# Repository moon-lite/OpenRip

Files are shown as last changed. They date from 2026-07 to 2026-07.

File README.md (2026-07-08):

# OpenRip

**Open-source launch telemetry for Beyblade X.** A ~$20 module that mounts
on top of the winder launcher — touching nothing but the outside — and
measures your launch RPM, beaming it to a web app over Bluetooth. No app
store, no account, no proprietary anything.

Think of it as an open alternative to the official Beybattle Pass — build
it, hack it, own your data — plus measurements the official one doesn't
take.

> ⚠️ **Project status: early prototype.** The firmware and web app exist,
> and the sensing approach is proven on a real launcher — a breadboard
> build reads clean RPM off the factory optical encoder (zero
> modification). There's no printed housing yet, so nothing here is ready
> to build unless you enjoy breadboards. Watch/star the repo to catch the
> first buildable release.

## What it does

- **Peak and release RPM** from an IR sensor reading the winder launcher's
  **factory encoder disc** through its built-in window — the exact surface
  the official module reads. **Zero launcher modification** (targeting ±2%
  of the official numbers)
- **True launch detection**: a low-force switch rides the launcher's
  bey-presence plunger, so tracking arms when a bey locks in and the
  release moment is timestamped — winding and re-insertion can't fake a
  launch
- **Live RPM + launch history** in a [web app](https://moon-lite.github.io/OpenRip/)
  that connects straight from Chrome — history stays in your browser, exports
  to CSV
- **Coming in v0.2:** launch angle relative to the stadium floor, and a rip
  smoothness score, via an IMU — data the official module doesn't capture

## What's in the box

| | |
|---|---|
| Brains | Seeed XIAO ESP32-C3 (~$5) |
| Sensor | TCRT5000 IR reflective sensor over the encoder window (~$1.50) |
| Presence | Subminiature microswitch riding the bey-release plunger (~$2) |
| Power | 100mAh LiPo, charges over USB-C (~$4) |
| Body | 3D-printed shell mounting on the winder launcher's top face |

Full parts list in [`hardware/BOM.csv`](hardware/BOM.csv), wiring in
[`hardware/wiring.md`](hardware/wiring.md).

## Try the app

The web app is live at **[moon-lite.github.io/OpenRip](https://moon-lite.github.io/OpenRip/)** —
no hardware needed to poke around: hit **SIM LAUNCH** to see it work.
Real connections need Chrome or Edge (Web Bluetooth doesn't exist on iOS).

## Roadmap

1. ✅ Firmware + web app written
2. ✅ **M0a: launcher characterized** — it has a factory optical encoder on
   the hook shaft, readable through a top-face window, plus a bey-presence
   plunger we piggyback for launch detection
3. ✅ **M0b: signal proof** — clean pulse train confirmed off a real
   launcher, launch RPM readings landing in the expected range
4. Printed housing + battery → first real device
   ← we are here
5. Public v0.1: build guide, video, flash-from-browser
6. v0.2: IMU for launch angle + smoothness

Details live in [SPEC.md](SPEC.md); build instructions grow in
[`docs/build-guide.md`](docs/build-guide.md) as each stage lands.

## For developers

```sh
cd firmware
pio run                 # build (serial-only)
pio run -t upload       # flash over USB-C
pio device monitor      # launch summaries at 115200 baud
```

Flashing from the browser (ESP Web Tools) ships with the first release —
the page is already stubbed at [`app/flash/`](app/flash/).

## Legal

BEYBLADE, BEYBLADE X, and BEYBATTLE PASS are trademarks of Tomy Company,
Ltd. and/or its licensee Hasbro, Inc. This project is not affiliated with,
sponsored by, or endorsed by either company; the names are used only to
describe compatibility ("works with Beyblade X winder launchers"). All
other trademarks are the property of their respective owners.

Licenses: firmware and app are MIT (see [LICENSE](LICENSE)); hardware and
models are CERN-OHL-P v2 (see [hardware/LICENSE](hardware/LICENSE) and
[models/LICENSE](models/LICENSE)).

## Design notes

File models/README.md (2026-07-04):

# Models

Housing CAD lands at M1: STEP + STL + Fusion source (.f3d), per SPEC.md §6.
Two-part clip-on shell (sensor arm + electronics bay) for the Takara Tomy
string launcher grip rail. Empty until sensor placement is validated at M0.

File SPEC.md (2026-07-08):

# OpenRip — Open Source Launch Telemetry for Beyblade X

**Status:** Draft v0.1 · **Licenses:** MIT (firmware/app), CERN-OHL-P v2 (hardware/models)

An open-source launcher-mounted module that measures launch RPM and launch angle for Beyblade X, reporting over BLE. Functional alternative to the official Beybattle Pass (BX-09) with data it doesn't capture (IMU) and an open protocol.

> Naming note: BEYBLADE, BEYBLADE X, and BEYBATTLE PASS are trademarks of Tomy Company, Ltd. and/or its licensee Hasbro, Inc. The official accessory's correct name is "Beybattle Pass" — always call it that (not "BattlePass"). Project name and repo must never use these marks except descriptively/nominatively ("compatible with Beyblade X launchers", "alternative to the official Beybattle Pass") and must never brand this project or its parts with them. Avoid Hasbro's slogan "LET IT RIP!" in product copy.

---

## 1. Goals

- **Zero launcher modification (hard requirement):** the device attaches externally (top-face mount over the factory encoder window) — nothing glued, pressed on, or altered. This is what keeps tournament use on the table.
- Measure peak launch RPM with accuracy comparable to the official Beybattle Pass (±2% target)
- Measure launch angle relative to a calibrated stadium plane
- Capture rip motion profile (accel curve, smoothness/consistency score)
- Report over BLE to a Web Bluetooth app — no app store, no account
- Fully reproducible from the repo: ~$20 in parts, a 3D printer, basic soldering
- Non-devs can flash firmware from a browser (ESP Web Tools)

## 2. Non-Goals (v0.x)

- String launcher support — v0.1 targets the winder launcher only (it has the factory optical encoder + window the sensor reads; string launcher sensing is a separate problem)
- Bey-side sensing (MEMS gyros saturate ~333 RPM; bey spins 5–12k)
- Position tracking / dead reckoning (IMU drift makes it useless)
- Battle outcome simulation — contact physics is out of scope
- Official app compatibility (protocol mimicry is a maybe-later, see §9)
- iOS support in v0.1 (Web Bluetooth is dead on iOS Safari)

## 3. Hardware

### v0.1 — Spin only (prototype)
| Part | Component | Est. cost |
|---|---|---|
| MCU | Seeed XIAO ESP32-C3 | $5 |
| Spin sensor | TCRT5000 IR reflective sensor, reading the winder launcher's **factory optical encoder** — a black/white two-segment disc visible through a ~5×5mm clear window on the top face, disc surface ~3mm below the window (this is what the official device reads; launcher stays stock). Peak sensitivity ~2.5mm matches the recess. Fallback: ITR8307 if the TCRT5000's signal swing is poor. | $1 |
| Bey presence | Subminiature low-force lever microswitch (SPDT, <0.5N actuation, Omron SS-01GL class) riding the launcher's spring plunger next to the encoder window — plunger sits below flush when empty, above flush with a bey locked, drops on release. Gates launch detection and timestamps release. | $1.50 |
| Battery | 401030 LiPo 100mAh (XIAO onboard charging) | $4 |
| Switch | SPDT slide | $0.50 |
| Housing | PLA, top-face mount over the encoder window (winder launcher) | ~$0.30 |

### v0.2 — Adds IMU
| Part | Component | Est. cost |
|---|---|---|
| IMU | LSM6DSO 6-axis (I2C) on launcher body | $5–8 |

**Signal-quality risk is now LOW** (M0a complete, 2026-07): the launcher ships with a purpose-built encoder disc — we're reading a surface designed to be read. The remaining unknown is IR contrast between the **translucent white** and black segments at the TCRT5000's wavelength (the disc was tuned for the official sensor, not ours); M0b measures it. Sticker fallbacks are obsolete.

### Small-batch path (later)
Custom PCB (ESP32-C3 module + bare LSM6DSO + TCRT5000), JLCPCB assembly: ~$8–12/unit @ qty 50.

## 4. Firmware

- **Stack:** PlatformIO, Arduino framework on ESP32-C3
- **RPM:** TCRT5000 reflectivity edges off the factory encoder disc → ADC threshold with hysteresis → interval timing. Two-segment disc = 1 pulse/encoder-rev; the disc sits on the hook shaft, so the window reads hook RPM directly (GEAR_RATIO = 1.0, kept configurable). Serial raw mode streams ADC samples for signal characterization.
- **Launch detection (presence-gated state machine):** IDLE → ARMED (plunger high = bey locked) → RIPPING (pulses while armed) → RELEASE (plunger falling edge). The release edge is timestamped; the record carries both **peak RPM** (min interval in the window) and **release RPM** (last pulse interval before the edge). Pulses are ignored while the plunger is low, which rejects winding/re-insertion as false launches. The 250ms pulse timeout survives only as a fallback when the release edge is missed; the switch input is debounced ~5ms. This matches the presumed official Beybattle Pass behavior (presence-gated tracking) and resolves the launch-detection ambiguity of a pure timeout.
- **IMU (v0.2):** LSM6DSO @ 416Hz over I2C, Madgwick fusion for orientation. Log accel/orientation ring buffer during rip; snapshot orientation at final encoder pulse = release angle.
- **Calibration:** button-triggered 2s rest on stadium floor (or rim jig) → zero orientation to stadium plane. Store in NVS.
- **BLE:** GATT server, custom service. Notify characteristic pushes a launch record post-launch; second characteristic for live RPM stream (training mode).
- **Power:** deep sleep after 5 min idle, wake on motion (IMU interrupt) or button.

### Launch record (v1 schema)
```
{
  seq: uint16,
  peak_rpm: uint16,
  release_rpm: uint16,       // from last pulse interval before the plunger release edge
  release_pitch_deg: int8,   // v0.2
  release_roll_deg: int8,    // v0.2
  rip_duration_ms: uint16,
  smoothness: uint8,         // 0-100, v0.2
  battery_pct: uint8
}
```

## 5. App

- **v0.1:** single-page Web Bluetooth app (vanilla JS or lightweight framework). Connect, live RPM, launch history in localStorage, CSV export.
- **Hosting:** GitHub Pages from the same repo.
- **v0.2+:** angle display, consistency graphs, session stats.

## 6. Housing

- Modeled in Fusion; publish **STEP + STL + source (.f3d)**
- Mounts on the **top face of the winder launcher**, over the factory encoder window — registers against the top-face geometry (not the grip rail)
- Holds the TCRT5000 centered over the ~5×5mm window at ~0mm standoff (sensor face flush to the window; the disc sits ~3mm below, at the sensor's sweet spot)
- Positions the bey-presence microswitch lever over the spring plunger adjacent to the window — actuated by the plunger's above-flush travel **without adding force that prevents bey seating** (low-force lever, free pivot)
- The microswitch mounts on an **adjustable carriage** (slot + M2 screw), not a fixed pocket: the plunger only rises ~1mm above flush, which is inside FDM print-tolerance stack-up. Builders calibrate the position once — slide until the switch **clicks with a bey seated and releases with it out** — then lock the screw.
- Two-part shell: sensor carrier + electronics bay
- Print settings documented; no supports as a design goal

## 7. Repo Layout

```
/firmware      PlatformIO project
/hardware      BOM.csv, wiring diagram, (later: KiCad)
/models        STEP, STL, Fusion source
/app           Web Bluetooth app (deployed via Pages)
/docs          Build guide, sensor placement photos, calibration
SPEC.md        this document
```

- GitHub Releases: firmware .bin + ESP Web Tools flash page per release
- Build guide gets a companion video (3 min, embedded in README)

## 8. Milestones

- **M0a — Mount characterization: ✅ complete (2026-07).** Winder launcher has a factory optical encoder — two-segment black/white disc through a ~5×5mm top-face window, disc ~3mm down. Findings: docs/sensor-characterization.md.
- **M0b — Sensor proof: ✅ complete (2026-07).** Breadboard IR sensor module (AO output) + ESP32: clean two-level signal off the encoder disc confirmed by hand-crank capture (tuned thresholds `SENSOR_THRESH_LOW 400` / `SENSOR_THRESH_HIGH 550`) and real launch RPM readings (peak 6746 and 6654, both within the expected 5,000–12,000 range). Findings: docs/sensor-characterization.md. *Go/no-go gate: passed.*
- **M1 — v0.1 device:** BLE launch records, printed housing, battery power
- **M2 — App:** Web Bluetooth page live on Pages, history + export
- **M3 — Public v0.1:** repo cleanup, build guide + video, ESP Web Tools flashing. Post to WBO + r/BeybladeX
- **M4 — v0.2 IMU:** angle, calibration, smoothness scoring
- **M5 (optional):** custom PCB + Tindie kits if community demand shows

## 9. Open Questions

1. Verify official Beybattle Pass mount geometry vs. designing our own top-face registration (affects M1 CAD)
2. SP↔RPM relationship — worth matching official app numbers for community comparability?
3. Mimic the reverse-engineered official BLE protocol (WBO thread) so community apps work, or stay clean with our own? Leaning own protocol + documented schema.
4. ~~Magnet on chuck: glue-on acceptable, or design a press-fit printed chuck sleeve so the launcher stays unmodified?~~ Superseded: any launcher modification is out (see Goals). Optical sensing through the mount opening replaces the magnet entirely.
5. ~~Pulses-per-rev off stock geometry~~ Resolved at M0a: two-segment encoder disc = 1 pulse per encoder rev. ~~Encoder-to-hook gear ratio~~ Resolved by teardown: the disc is mounted directly on the hook shaft (16T gear), downstream of the gear train — the window reads hook RPM directly (GEAR_RATIO = 1.0).
6. Tournament legality is TO-discretion even at zero modification — most rulesets allow *official* accessories, not arbitrary attachments. Frame the device as training/casual-legal, tournament-pending; zero modification keeps the door open, it doesn't guarantee entry.

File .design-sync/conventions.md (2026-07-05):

# open=rip design conventions

open=rip is a **light, airy, editorial** aesthetic — a clean zine, not a
dashboard. Paper-white ground, ink typography, hairline rules instead of
boxes, one teal accent for live data and the brand mark, italics for
captions and asides. Screens should read like a well-set magazine page
about your launches.

## Setup

No provider is required. Components style themselves via CSS custom
properties defined in `styles.css` (`:root` scope) — make sure that
stylesheet is loaded. **Give the page a paper ground**: set
`background: var(--or-bg)` on the page/root container; components assume a
light ground and look wrong on dark.

The single family (Instrument Sans, with true italics) loads via the Google
Fonts `@import` already inside `styles.css` — nothing to add. Hierarchy
comes from weight and rules, not color: 700 for numerals/headlines, 600 for
buttons, 500 for labels, 400 for body, *italic* for captions and notes.

## Styling idiom

There are **no utility classes**. Use the components' props for the
controls; for your own layout glue (containers, grids, spacing) write plain
CSS or inline styles using the tokens:

- Surfaces: `--or-bg` (paper), `--or-bg-raise` (white), `--or-line` (hairlines), `--or-line-strong` (ink rules)
- Ink: `--or-ink` (primary), `--or-ink-dim` (labels/captions)
- Signals: `--or-accent` (teal — brand, live data, links), `--or-accent-wash` (faint teal fill), `--or-danger` (coral — destructive only)
- Type: `--or-font` (the only family — vary weight and italic, not face)
- Spacing: `--or-space-xs/sm/md/lg/xl` (4/8/16/24/40px)
- Corners: `--or-radius-pill` (controls are pills), `--or-radius` (12px, rare — most surfaces are unboxed)

Prefer **rules over boxes**: separate sections with `Divider` or a 1px
`--or-line` border, not cards. Numerals get
`font-feature-settings: "tnum"` so columns align. Labels are small,
lowercase, `--or-ink-dim`. Generous whitespace — when in doubt, add space,
not decoration.

## Components (window.OpenRipDesign)

`Button` (variant: primary | ghost | danger — primary is the solid ink
pill, one per screen), `StatusChip` (online + label; hairline pill),
`Gauge` (value/max/unit/size — the hero readout, one per screen),
`StatTile` (label + value; top-rule index block, "—" for empty), `Divider`
(hairline ink rule), `Banner` (italic margin note with teal left rule),
`Wordmark` (the lowercase open=rip mark, top-left), `DataTable`
(columns/rows/emptyText — hairline rows, no box).

## Where the truth lives

Read `styles.css` (tokens at top, component classes below) before inventing
styles; per-component APIs are in each `<Name>.d.ts`.

## Idiomatic screen skeleton

```jsx
const { Wordmark, StatusChip, Button, Divider, Gauge, StatTile } = window.OpenRipDesign;

<div style={{ background: "var(--or-bg)", minHeight: "100vh", padding: "var(--or-space-xl)" }}>
  <header style={{ display: "flex", justifyContent: "space-between", alignItems: "flex-end", paddingBottom: "var(--or-space-md)" }}>
    <Wordmark subtitle="launch telemetry · vol 0.1" />
    <div style={{ display: "flex", gap: "var(--or-space-sm)", alignItems: "center" }}>
      <StatusChip online label="Linked" />
      <Button variant="primary">Disconnect</Button>
    </div>
  </header>
  <Divider />
  <main style={{ display: "flex", gap: "var(--or-space-xl)", alignItems: "center", padding: "var(--or-space-xl) 0" }}>
    <Gauge value={8450} unit="rpm · live" />
    <div style={{ display: "grid", gridTemplateColumns: "1fr 1fr", gap: "var(--or-space-lg)" }}>
      <StatTile label="session best" value="11,240" />
      <StatTile label="launches" value="14" />
    </div>
  </main>
</div>
```

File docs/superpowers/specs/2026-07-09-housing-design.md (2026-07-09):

# M1 Housing Design — Blender + MCP Workflow

**Status:** Approved (brainstorming session 2026-07-09) — implementation not yet started.

## Context

M0a (mount characterization) and M0b (sensor proof) are complete: the winder
launcher's factory optical encoder is confirmed readable through its
top-face window with zero modification, and a breadboard build has proven
clean RPM readings end-to-end, including presence-gated launch detection via
a microswitch on the launcher's spring plunger. See
`docs/sensor-characterization.md` for the validated data.

M1 is next per `SPEC.md` §8: printed housing, battery power, BLE launch
records. This spec covers only the **housing** piece of M1. No CAD exists
yet — `models/` currently holds only `LICENSE` and a stub `README.md`, and
that stub's description ("clip-on shell for the string launcher grip rail")
is stale/incorrect: `SPEC.md` §6 correctly specifies a **top-face** mount
over the encoder window, registering against top-face geometry, not the
grip rail. This work corrects that stub as part of landing the real design.

## Goals

- Design a two-part printable shell that mounts non-destructively on the
  winder launcher's top face and holds:
  - the sensor breakout module (VCC/GND/AO/DO, onboard LM393 comparator —
    the part actually validated at M0b, not the bare TCRT5000 originally
    speced in the BOM) positioned over the ~5×5mm encoder window
  - the bey-presence microswitch on an adjustable carriage (slot + M2
    screw/heat-set insert), as already described in `docs/build-guide.md`
  - the Seeed XIAO ESP32-C3
  - the 401030 LiPo battery
  - an SPDT power slide switch
- Drive the modeling through Claude Code via a Blender MCP connection, using
  a phone-captured 3D scan of the launcher's top face as the registration
  reference surface, so the mount fits the launcher's real geometry rather
  than estimated dimensions.
- Deliver STEP + STL + Blender source (`.blend`), updating `SPEC.md` §6's
  deliverable format away from Fusion's `.f3d` (no longer applicable since
  we're not using Fusion 360).

## Non-goals

- Finalizing the exact registration/clip geometry in this document — that's
  a first-CAD-iteration decision, made after the scan data exists, not
  something to lock in blind.
- IMU mounting — that's M4/v0.2 scope, not this milestone.
- Any launcher modification. Zero-modification is a hard requirement
  (`SPEC.md` §1) carried over unchanged: the mount must be a removable,
  non-destructive friction-fit/clip — nothing glued, nothing pressed in
  permanently, nothing altered on the launcher itself.

## Decisions from brainstorming

- **Geometry source:** phone 3D scan (LiDAR/photogrammetry) of the bare
  launcher top face, exported as a mesh (OBJ/STL).
- **Sensor footprint:** design around the breakout module already wired and
  validated at M0b, not the bare TCRT5000 from the original BOM. (BOM/
  wiring.md's "buy bare sensors, not modules" note is now superseded for
  this build and should be revisited/updated separately when this housing
  work lands.)
- **Print setup:** the builder has their own FDM printer, so a fast
  print-and-check iteration loop is available and expected to be used.
- **Modeling role:** hands-off — Claude drives the Blender modeling via
  MCP; the builder reviews rendered screenshots/exports and handles the
  physical scan capture and print-fit testing.
- **Tooling:** Blender + a Blender MCP server for modeling (chosen over
  FreeCAD+MCP and OpenSCAD specifically because it handles an imported
  organic scan mesh — for boolean registration fits — far better than
  either alternative). FreeCAD is used only as a narrow, scripted,
  non-MCP conversion bridge at final export time (STL → STEP), since
  Blender's native export path is STL and STEP is a required deliverable.

## Pipeline

```
Phone scan (bare launcher top face, no breadboard in the way)
        │  export OBJ/STL
        ▼
Blender  ──MCP──▶  Claude scripts the model:
  - import scan as a fixed reference (never modified/exported itself)
  - build shell geometry as separate mesh objects, booleaned
    against the scan surface for a snug registration fit
  - position pockets: sensor module, XIAO, battery, switch carriage
  - render viewport screenshots after each major step for review
        │  export STL per part
        ▼
FreeCAD (headless, scripted) ──▶ STL → STEP conversion
        │
        ▼
Print → test-fit on the real launcher → adjust dimensions → reprint
        │
        ▼
Final deliverables committed: STEP + STL + Blender source
```

The scan mesh itself is a large binary file and is never committed — see
Repo conventions below.

## Components

- **Sensor carrier** — holds the sensor breakout module's PCB centered over
  the launcher's ~5×5mm window, at whatever standoff the module's photo-dome
  height requires (pinned down by directly measuring the module during
  modeling, not assumed up front). Also carries the **adjustable switch
  carriage**: a slot + M2 screw (or heat-set insert) letting the microswitch
  slide toward/away from the plunger and lock once calibrated, per the
  existing calibration procedure in `docs/build-guide.md`.
- **Electronics bay** — holds the XIAO ESP32-C3, the 401030 LiPo battery,
  and the SPDT power slide switch. Includes a USB-C cutout (charging/
  reflashing without disassembly) and a slide-switch cutout (actuator tab
  reachable from outside).
- **Joining the two shell halves** — snap-fit cantilever tabs by default,
  not screws, so the enclosure opens for battery access without needing
  fasteners. The M2 screw/insert is reserved solely for the switch carriage
  lock.
- **Mounting to the launcher** — a friction-fit/spring-clip that registers
  against whatever real lip or edge the scan reveals on the top face.
  Exact geometry is a first-CAD-iteration decision (see Non-goals). Must
  stay fully removable and non-destructive — no adhesive, nothing pressed
  permanently into the launcher.
- **Print approach** — PLA, ~1.6–2mm walls, split lines and overhangs
  chosen to preserve the "no supports" goal from `SPEC.md` §6.

## Repo & tooling conventions

- `models/scans/` — gitignored. Holds raw phone-scan exports. Never
  committed — large, binary, and not useful in git history.
- `models/housing/` — the actual deliverables: the Blender `.blend`
  source, exported `.stl` per part, and the converted `.step`. Satisfies
  `SPEC.md` §6's "STEP + STL + source" once that section's format note is
  updated from `.f3d` to `.blend`.
- One-time environment setup (implementation-plan concern, noted here for
  completeness): Blender installed locally, the Blender MCP addon enabled,
  and its server running so Claude Code can connect to a live Blender
  session.
- Doc updates bundled into this work: fix `models/README.md`'s stale
  "grip rail" description; update `SPEC.md` §6's deliverable format; give
  `docs/build-guide.md`'s M1 section real modeling-workflow content once
  the pipeline exists (same pattern already used for M0b).

## Print-and-validate loop / acceptance criteria

At least one print-and-adjust cycle is expected — a scan-based fit is a
strong starting point, not a guaranteed first-try perfect one. Print the
sensor carrier first (smaller, most fit-critical) before committing to the
full electronics bay, so a bad registration fit is caught cheaply.

The M1 housing is done when, on a printed and assembled unit:

- The shell clips onto the launcher's top face snugly, without wobble, and
  comes off cleanly — no tools, no residue, no interference with normal
  winding, bey-seating, or grip.
- With the housing mounted, a raw-mode ADC check (same procedure as M0b)
  still shows a clean two-level signal — confirms the housing didn't move
  the sensor off its validated working distance.
- The switch carriage calibration procedure in `docs/build-guide.md`
  passes: `ARMED` with a bey seated, `IDLE` with it removed, no resistance
  to seating.
- USB-C and the power switch are reachable without opening the shell; the
  two halves snap together and reopen cleanly for battery access.
- A real rip-cord launch with the housing mounted produces a launch report
  matching the bench validation (peak RPM in the expected 5,000–12,000
  range, plausible pulse count).

## Open questions (deferred to implementation)

- Exact top-face registration/clip geometry — decided from the scan data
  in the first CAD iteration, not before.
- Blender → STEP export path — confirm at implementation time whether a
  native Blender STEP export addon is usable, or whether the FreeCAD
  conversion bridge described above is needed.
- Sensor module standoff/orientation inside its pocket — pinned down by
  direct measurement of the physical module during modeling.

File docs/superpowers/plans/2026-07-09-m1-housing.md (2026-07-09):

# M1 Housing Implementation Plan

> **For agentic workers:** REQUIRED SUB-SKILL: Use superpowers:subagent-driven-development (recommended) or superpowers:executing-plans to implement this plan task-by-task. Steps use checkbox (`- [ ]`) syntax for tracking.

**Goal:** Produce a printable, non-destructive two-part shell that mounts on the winder launcher's top face and houses the M0b-validated sensor module, presence microswitch, XIAO ESP32-C3, LiPo battery, and power switch — modeled in Blender via an MCP connection against a real 3D scan of the launcher.

**Architecture:** A phone scan of the launcher's top face becomes a fixed reference mesh in Blender; Claude scripts the shell geometry (via `bpy`, driven through a Blender MCP server) as boolean operations against that reference and against a set of measured component dimensions. Finished parts export to STL, get converted to STEP via a small headless FreeCAD script, and get physically print-tested in a loop against the acceptance criteria from the design spec.

**Tech Stack:** Blender (with a Blender MCP addon/server), Python (`bpy` inside Blender; `trimesh` for mesh verification outside it), FreeCAD (headless, scripted, STEP conversion only), PlatformIO firmware already in place (unaffected by this plan).

## Global Constraints

- Zero launcher modification (hard requirement, `SPEC.md` §1): the mount must be a removable, non-destructive friction-fit/clip. Never glue, drill, or permanently press anything into the launcher.
- Print goal: PLA, no supports (`SPEC.md` §6). Design overhangs/split-lines accordingly.
- Deliverables per `SPEC.md` §6: STEP + STL + source. Source format is `.blend` (not `.f3d` — updated by this plan, see Task 1).
- Repo layout (design spec): raw scans in `models/scans/` (gitignored, never committed); finished deliverables in `models/housing/`.
- Sensor: the breakout module already wired and validated at M0b (VCC/GND/AO/DO, onboard LM393 comparator) — not the bare TCRT5000 from the original BOM.
- Design spec of record: `docs/superpowers/specs/2026-07-09-housing-design.md`. This plan implements it; if anything here conflicts with it, the spec wins and this plan should be corrected.

---

### Task 1: Repo scaffolding and doc corrections

**Files:**
- Modify: `.gitignore`
- Modify: `models/README.md`
- Modify: `SPEC.md` (§6 Housing)
- Create: `models/scans/.gitkeep`
- Create: `models/housing/.gitkeep`

**Interfaces:**
- Produces: `models/scans/` (gitignored directory for raw scan exports), `models/housing/` (tracked directory for shell deliverables) — every later task reads/writes these exact paths.

- [ ] **Step 1: Add the new gitignore entries**

Add to `.gitignore` (after the existing `# PlatformIO` block, in a new section):

```
# 3D scan captures (raw phone-scan exports — large binaries, never committed)
models/scans/*
!models/scans/.gitkeep
```

- [ ] **Step 2: Create the two directories with placeholder files**

```bash
mkdir -p models/scans models/housing
touch models/scans/.gitkeep models/housing/.gitkeep
```

- [ ] **Step 3: Fix the stale housing description in `models/README.md`**

Replace the file's contents with:

```markdown
# Models

Housing CAD: STEP + STL + Blender source (`.blend`), per SPEC.md §6.
Two-part shell (sensor carrier + electronics bay) for the winder
launcher's **top face**, registering against the top-face geometry captured
in a 3D scan — not the grip rail. See
`docs/superpowers/specs/2026-07-09-housing-design.md` for the design and
`docs/superpowers/plans/2026-07-09-m1-housing.md` for the build process.

- `scans/` — raw phone-scan exports (gitignored, not committed)
- `housing/` — finished deliverables: `.blend` source, `.stl` per part, `.step`
```

- [ ] **Step 4: Update `SPEC.md` §6's deliverable format**

Find this line in `SPEC.md` §6 (Housing):

```
- Modeled in Fusion; publish **STEP + STL + source (.f3d)**
```

Replace with:

```
- Modeled in Blender (scripted via MCP against a 3D scan of the launcher); publish **STEP + STL + source (.blend)**
```

- [ ] **Step 5: Verify and commit**

```bash
git status
git add .gitignore models/README.md SPEC.md models/scans/.gitkeep models/housing/.gitkeep
git commit -m "Scaffold models/scans and models/housing; fix stale housing docs"
```

Expected: `git status` after the commit shows a clean tree, and `models/scans/` and `models/housing/` exist with a `.gitkeep` each.

---

### Task 2: Blender MCP environment setup and connectivity smoke test

**Files:**
- Create: `models/housing/smoke_test.py` (temporary verification script, deleted at the end of this task)

**Interfaces:**
- Produces: a confirmed-working Blender MCP connection and the exact tool name(s) it exposes (recorded in this task's commit message for later tasks to reference) — every later Blender task depends on this.

- [ ] **Step 1 (human action): Install Blender**

If not already installed: `brew install --cask blender`. Confirm with:

```bash
/Applications/Blender.app/Contents/MacOS/Blender --version
```

Expected: prints a Blender version string (4.x).

- [ ] **Step 2 (human action): Install and start a Blender MCP server**

Install the Blender MCP addon (the widely-used `BlenderMCP` project — search "Blender MCP" if the exact install steps below have drifted from the current release):

```bash
pipx install uv
uvx blender-mcp
```

Then in Blender: install the addon zip from the same project into Blender's Preferences → Add-ons, enable it, and in the 3D viewport's sidebar (N-panel) find the "BlenderMCP" tab and click "Connect to Claude" (or "Start Server" — exact label depends on the addon version). Leave Blender open and the server running for the rest of this plan.

- [ ] **Step 3: Discover the exposed MCP tool(s)**

In this session, run:

```
ToolSearch({query: "blender", max_results: 10})
```

Expected: one or more `mcp__*blender*` tools appear (commonly something like `execute_blender_code`, `get_scene_info`, `get_object_info` — the connected server's actual names). Record the exact tool names you see — every subsequent task in this plan refers to "the Blender code-execution tool" meaning whichever one of these runs arbitrary Python inside Blender.

- [ ] **Step 4: Run a smoke test through the discovered tool**

Using the code-execution tool found in Step 3, run this Python inside Blender:

```python
import bpy
bpy.ops.object.select_all(action='DESELECT')
bpy.ops.mesh.primitive_cube_add(size=0.02, location=(0, 0, 0.01))  # 20mm test cube
bpy.context.object.name = "SmokeTestCube"
bpy.ops.object.camera_add(location=(0.1, -0.1, 0.08), rotation=(1.1, 0, 0.78))
bpy.context.scene.camera = bpy.context.object
print("Objects in scene:", [o.name for o in bpy.data.objects])
```

Expected output includes `SmokeTestCube` in the printed object list — confirms the MCP round-trip (send code, execute in Blender, return stdout) works.

- [ ] **Step 5: Confirm a render/screenshot path works**

Using whatever screenshot/render tool the MCP server exposes (found via the same `ToolSearch` in Step 3 — commonly a `get_viewport_screenshot`-style tool), capture one image of the current viewport. Expected: an image showing the test cube.

- [ ] **Step 6: Clean up the smoke test object**

```python
import bpy
bpy.data.objects.remove(bpy.data.objects["SmokeTestCube"], do_unlink=True)
```

No commit for this task — nothing durable was created (the addon install and running server are local machine state, not repo state).

---

### Task 3: Capture launcher measurements and 3D scan (human action + verification)

**Files:**
- Create: `models/housing/measurements.py`
- Create: `models/scans/launcher-top-face.stl` (or `.obj` — gitignored, not committed)
- Create: `models/housing/verify_scan.py`

**Interfaces:**
- Produces: `models/housing/measurements.py` — a Python module of named float constants, all in millimeters, that every subsequent modeling task imports by name. Exact names are fixed by Step 2 below; later tasks must use these names verbatim.
- Produces: `models/scans/launcher-top-face.stl` — the reference mesh every modeling task loads.

- [ ] **Step 1 (human action): Scan the bare launcher top face**

Remove the breadboard sensor/switch from the launcher so the scan captures the unobstructed top face (window, plunger, and surrounding contour). Using a LiDAR-capable phone (or a photogrammetry app), scan the top face and export as OBJ or STL. Copy the file to:

```bash
cp <wherever your phone synced the export> models/scans/launcher-top-face.stl
```

- [ ] **Step 2 (human action): Measure components and fill in `measurements.py`**

Create `models/housing/measurements.py` with this exact content, replacing every `None` with a measured value in millimeters (calipers for anything not already noted as a known spec):

```python
"""
Component and launcher dimensions for the M1 housing, all in millimeters.
Filled in from direct measurement (calipers) unless noted otherwise.
Re-run `verify_scan.py` after editing this file to sanity-check units.
"""

# --- Launcher top face (measured relative to the scan's own origin — see
# verify_scan.py Step 1 for how to read these off the scan mesh) ---
WINDOW_CENTER_X_MM = None       # encoder window center, X in scan coordinates
WINDOW_CENTER_Y_MM = None       # encoder window center, Y in scan coordinates
WINDOW_SIZE_MM = 5.0            # confirmed at M0a: ~5x5mm clear window
PLUNGER_CENTER_X_MM = None      # spring plunger center, X in scan coordinates
PLUNGER_CENTER_Y_MM = None      # spring plunger center, Y in scan coordinates
PLUNGER_TRAVEL_MM = 1.0         # confirmed at M0a/M0b: ~1mm above flush when locked

# --- Sensor breakout module (VCC/GND/AO/DO, the part validated at M0b) ---
MODULE_PCB_LENGTH_MM = None
MODULE_PCB_WIDTH_MM = None
MODULE_PCB_THICKNESS_MM = None
MODULE_DOME_PROTRUSION_MM = None   # how far the IR domes stick out below the PCB underside

# --- Seeed XIAO ESP32-C3 ---
# Published board spec is ~21 x 17.5mm; confirm with calipers, the exact
# PCB can vary slightly batch to batch.
XIAO_LENGTH_MM = None
XIAO_WIDTH_MM = None
XIAO_THICKNESS_MM = None

# --- Battery: 401030 LiPo (BOM part BT1) ---
# "401030" naming convention is thickness x width x length in mm; confirm
# with calipers since exact cells vary.
BATTERY_THICKNESS_MM = None   # nominal 4.0
BATTERY_WIDTH_MM = None       # nominal 10.0
BATTERY_LENGTH_MM = None      # nominal 30.0

# --- Power switch: SS12D00 SPDT mini slide switch (BOM part SW1) ---
SWITCH_LENGTH_MM = None
SWITCH_WIDTH_MM = None
SWITCH_HEIGHT_MM = None

# --- Microswitch: D2F-01FL class (BOM part SW2) ---
MICROSWITCH_BODY_LENGTH_MM = None
MICROSWITCH_BODY_WIDTH_MM = None
MICROSWITCH_LEVER_LENGTH_MM = None

# --- Fastener ---
M2_SCREW_CLEARANCE_HOLE_MM = 2.4   # standard M2 clearance hole diameter
```

- [ ] **Step 3: Write the scan verification script**

Create `models/housing/verify_scan.py`:

```python
"""
Sanity-checks the raw scan mesh before any modeling work starts.
Run with: python3 models/housing/verify_scan.py
Requires: pip install trimesh
"""
import sys
import trimesh

SCAN_PATH = "models/scans/launcher-top-face.stl"

def main():
    try:
        mesh = trimesh.load(SCAN_PATH)
    except Exception as e:
        print(f"FAIL: could not load {SCAN_PATH}: {e}")
        sys.exit(1)

    print(f"Loaded {SCAN_PATH}")
    print(f"  vertices: {len(mesh.vertices)}")
    print(f"  faces:    {len(mesh.faces)}")
    print(f"  bounding box (mm): {mesh.bounding_box.extents}")
    print(f"  watertight: {mesh.is_watertight}")

    extents = mesh.bounding_box.extents
    # A real launcher top-face scan should span tens of millimeters, not
    # meters (unit mismatch) or fractions of a millimeter (degenerate scan).
    if not all(5.0 <= e <= 300.0 for e in extents):
        print("FAIL: bounding box outside 5-300mm range on some axis — "
              "check the scan's export units (should be mm).")
        sys.exit(1)

    print("PASS: scan mesh loads and dimensions look plausible.")

if __name__ == "__main__":
    main()
```

- [ ] **Step 4: Run the verification script**

```bash
pip3 install --user trimesh
python3 models/housing/verify_scan.py
```

Expected: `PASS: scan mesh loads and dimensions look plausible.` If it fails on the bounding-box check, the scan was likely exported in meters instead of millimeters — re-export or scale it before continuing.

- [ ] **Step 5: Commit the measurements and verification script (not the scan itself)**

```bash
git add models/housing/measurements.py models/housing/verify_scan.py
git status   # confirm models/scans/launcher-top-face.stl is NOT listed
git commit -m "Add M1 housing measurements and scan verification script"
```

---

### Task 4: Import the scan and establish a shared reference frame in Blender

**Files:**
- Create: `models/housing/blender_scripts/01_setup_reference.py`

**Interfaces:**
- Consumes: `models/scans/launcher-top-face.stl`, `models/housing/measurements.py` (`WINDOW_CENTER_X_MM`, `WINDOW_CENTER_Y_MM`, `PLUNGER_CENTER_X_MM`, `PLUNGER_CENTER_Y_MM`)
- Produces: a Blender scene (saved as `models/housing/openrip-housing.blend`) containing three named objects every later task refers to by name: `LauncherScan` (the imported, never-modified reference mesh), `WindowCenter` (an Empty marking the encoder window's center), `PlungerCenter` (an Empty marking the plunger's center) — both Empties placed in world space at Z=0 on the scan's top face.

- [ ] **Step 1: Write the setup script**

Create `models/housing/blender_scripts/01_setup_reference.py` (this is authored here, then its contents get sent through the Blender code-execution tool from Task 2 — Blender's `bpy` only exists inside a running Blender process, it cannot be run as a standalone `python3` script):

```python
import bpy
import sys
sys.path.insert(0, "/Users/neilmedici/Documents/GitHub/OpenRip/models/housing")
import measurements as m

SCAN_PATH = "/Users/neilmedici/Documents/GitHub/OpenRip/models/scans/launcher-top-face.stl"
BLEND_SAVE_PATH = "/Users/neilmedici/Documents/GitHub/OpenRip/models/housing/openrip-housing.blend"

# Clear the default scene
bpy.ops.wm.read_factory_settings(use_empty=True)

# Import the scan as the fixed reference — this object is never exported
# or boolean-modified itself, only used as a boolean/measurement target.
bpy.ops.wm.stl_import(filepath=SCAN_PATH)
scan = bpy.context.selected_objects[0]
scan.name = "LauncherScan"

# Mark the window and plunger centers as Empties, from measurements.py.
# Z=0 assumes the scan's own coordinate system has the top face at Z=0;
# adjust here once if the raw scan's origin differs.
bpy.ops.object.empty_add(type='PLAIN_AXES', radius=0.002,
                          location=(m.WINDOW_CENTER_X_MM / 1000,
                                    m.WINDOW_CENTER_Y_MM / 1000, 0))
bpy.context.object.name = "WindowCenter"

bpy.ops.object.empty_add(type='PLAIN_AXES', radius=0.002,
                          location=(m.PLUNGER_CENTER_X_MM / 1000,
                                    m.PLUNGER_CENTER_Y_MM / 1000, 0))
bpy.context.object.name = "PlungerCenter"

bpy.ops.wm.save_as_mainfile(filepath=BLEND_SAVE_PATH)
print("Saved:", BLEND_SAVE_PATH)
print("Objects:", [o.name for o in bpy.data.objects])
```

Note: Blender's units are meters internally — this plan works in mm via `measurements.py` and divides by 1000 at the `bpy` boundary, consistently, in every task.

- [ ] **Step 2: Run it through the Blender code-execution tool**

Send the script's contents through the tool identified in Task 2 Step 3.

- [ ] **Step 3: Verify**

Expected printed output: `Objects: ['LauncherScan', 'WindowCenter', 'PlungerCenter']` and the save path confirmation. Take a viewport screenshot (same tool as Task 2 Step 5) — expected: the scanned mesh visible with two small axis markers sitting on its top face roughly at the window and plunger locations.

- [ ] **Step 4: Commit the script (not the scan, not the .blend yet — that lands in Task 8 once parts are added)**

```bash
mkdir -p models/housing/blender_scripts
git add models/housing/blender_scripts/01_setup_reference.py
git commit -m "Add Blender reference-frame setup script for M1 housing"
```

---

### Task 5: Model the sensor carrier and switch carriage

**Files:**
- Create: `models/housing/blender_scripts/02_sensor_carrier.py`
- Create: `models/housing/verify_part.py`

**Interfaces:**
- Consumes: `LauncherScan`, `WindowCenter`, `PlungerCenter` (from Task 4); `MODULE_PCB_*`, `MICROSWITCH_*`, `M2_SCREW_CLEARANCE_HOLE_MM` (from `measurements.py`)
- Produces: a `SensorCarrier` mesh object in the `.blend` scene, and `models/housing/exports/sensor_carrier.stl`. Later tasks (Task 7 mounting clip, Task 8 export) read this object by name.

- [ ] **Step 1: Write the modeling script**

Create `models/housing/blender_scripts/02_sensor_carrier.py`:

```python
import bpy
import sys
sys.path.insert(0, "/Users/neilmedici/Documents/GitHub/OpenRip/models/housing")
import measurements as m

MM = 0.001  # bpy works in meters; every *_mm value below is converted via mm()
CLEARANCE_MM = 0.3      # per-side fit clearance for a snug (not press) pocket fit
FLOOR_THICKNESS_MM = 1.5  # solid material left under the pocket, and the walls' target thickness

def mm(v):
    return v * MM

# Sensor module pocket: a rectangular recess sized to the module's PCB
# plus clearance, deep enough for the PCB thickness plus dome protrusion,
# with FLOOR_THICKNESS_MM of solid material left below it. The block's
# own height is the pocket depth plus that floor — NOT the same number.
pocket_l_mm = m.MODULE_PCB_LENGTH_MM + 2 * CLEARANCE_MM
pocket_w_mm = m.MODULE_PCB_WIDTH_MM + 2 * CLEARANCE_MM
pocket_depth_mm = m.MODULE_PCB_THICKNESS_MM + m.MODULE_DOME_PROTRUSION_MM + 0.5
block_l_mm = pocket_l_mm + 4.0   # 2mm wall each side
block_w_mm = pocket_w_mm + 4.0
block_h_mm = pocket_depth_mm + FLOOR_THICKNESS_MM

window = bpy.data.objects["WindowCenter"]
plunger = bpy.data.objects["PlungerCenter"]

# Outer block. primitive_cube_add(size=1) makes a 1m-per-side cube, so
# object.scale == the final dimensions in meters directly (no extra factor).
bpy.ops.mesh.primitive_cube_add(
    size=1, location=(window.location.x, window.location.y, mm(block_h_mm) / 2)
)
carrier = bpy.context.object
carrier.name = "SensorCarrier"
carrier.scale = (mm(block_l_mm), mm(block_w_mm), mm(block_h_mm))
bpy.ops.object.transform_apply(location=False, rotation=False, scale=True)

# Cut the module pocket down from the top, leaving FLOOR_THICKNESS_MM intact.
cutter_z = mm(block_h_mm) - mm(pocket_depth_mm) / 2
bpy.ops.mesh.primitive_cube_add(
    size=1, location=(window.location.x, window.location.y, cutter_z)
)
cutter = bpy.context.object
cutter.scale = (mm(pocket_l_mm), mm(pocket_w_mm), mm(pocket_depth_mm) + mm(1.0))
bpy.ops.object.transform_apply(location=False, rotation=False, scale=True)

mod = carrier.modifiers.new(name="PocketCut", type='BOOLEAN')
mod.operation = 'DIFFERENCE'
mod.object = cutter
bpy.context.view_layer.objects.active = carrier
bpy.ops.object.modifier_apply(modifier="PocketCut")
bpy.data.objects.remove(cutter, do_unlink=True)

# Switch carriage slot: a through-slot near the plunger, long enough to
# slide the microswitch body toward/away from it.
slot_travel_mm = 4.0  # adjustable range, per docs/build-guide.md carriage note
slot_l_mm = m.MICROSWITCH_BODY_LENGTH_MM + slot_travel_mm
slot_w_mm = m.MICROSWITCH_BODY_WIDTH_MM + 2 * CLEARANCE_MM

bpy.ops.mesh.primitive_cube_add(
    size=1, location=(plunger.location.x, plunger.location.y, mm(block_h_mm) / 2)
)
slot_cutter = bpy.context.object
slot_cutter.scale = (mm(slot_l_mm), mm(slot_w_mm), mm(block_h_mm) + mm(2.0))
bpy.ops.object.transform_apply(location=False, rotation=False, scale=True)

mod2 = carrier.modifiers.new(name="SlotCut", type='BOOLEAN')
mod2.operation = 'DIFFERENCE'
mod2.object = slot_cutter
bpy.context.view_layer.objects.active = carrier
bpy.ops.object.modifier_apply(modifier="SlotCut")
bpy.data.objects.remove(slot_cutter, do_unlink=True)

bpy.ops.wm.save_mainfile()
print("SensorCarrier bounding box (m):", carrier.dimensions)
```

- [ ] **Step 2: Run it through the Blender code-execution tool, then export the part**

After running the script above, run this through the same tool to export:

```python
import bpy
bpy.ops.object.select_all(action='DESELECT')
bpy.data.objects["SensorCarrier"].select_set(True)
bpy.ops.wm.stl_export(
    filepath="/Users/neilmedici/Documents/GitHub/OpenRip/models/housing/exports/sensor_carrier.stl",
    export_selected_objects=True
)
print("Exported sensor_carrier.stl")
```

- [ ] **Step 3: Write the dimension verification script**

Create `models/housing/verify_part.py`:

```python
"""
Checks an exported housing part's bounding box against measurements.py.
Run with: python3 models/housing/verify_part.py sensor_carrier
Requires: pip install trimesh
"""
import sys
import trimesh
import measurements as m

PARTS = {
    "sensor_carrier": {
        "path": "models/housing/exports/sensor_carrier.stl",
        # (min_l, min_w, min_h) the part must be at least this big to
        # actually contain its pocket contents.
        "min_extents_mm": (
            m.MODULE_PCB_LENGTH_MM,
            m.MODULE_PCB_WIDTH_MM,
            m.MODULE_PCB_THICKNESS_MM,
        ),
    },
}

def main():
    if len(sys.argv) != 2 or sys.argv[1] not in PARTS:
        print(f"Usage: python3 verify_part.py [{'|'.join(PARTS)}]")
        sys.exit(1)

    spec = PARTS[sys.argv[1]]
    mesh = trimesh.load(spec["path"])
    if not mesh.is_watertight:
        print(f"FAIL: {spec['path']} is not watertight (not print-ready).")
        sys.exit(1)

    extents = sorted(mesh.bounding_box.extents)
    minimums = sorted(spec["min_extents_mm"])
    if any(e < mn for e, mn in zip(extents, minimums)):
        print(f"FAIL: {spec['path']} bounding box {extents} smaller than "
              f"required minimums {minimums}.")
        sys.exit(1)

    print(f"PASS: {spec['path']} is watertight and at least {minimums} mm.")

if __name__ == "__main__":
    main()
```

- [ ] **Step 4: Run the verification**

```bash
cd models/housing
python3 verify_part.py sensor_carrier
```

Expected: `PASS: ...`. If it fails watertight, the boolean operations in Step 1 left a non-manifold mesh — check for zero-thickness overlaps between the pocket/slot cutters and the outer block.

- [ ] **Step 5: Commit**

```bash
mkdir -p models/housing/exports
git add models/housing/blender_scripts/02_sensor_carrier.py models/housing/verify_part.py models/housing/exports/sensor_carrier.stl
git commit -m "Model M1 sensor carrier + switch carriage slot"
```

---

### Task 6: Model the electronics bay

**Files:**
- Create: `models/housing/blender_scripts/03_electronics_bay.py`
- Modify: `models/housing/verify_part.py` (add an `"electronics_bay"` entry to `PARTS`)

**Interfaces:**
- Consumes: `XIAO_*`, `BATTERY_*`, `SWITCH_*` (from `measurements.py`)
- Produces: an `ElectronicsBay` mesh object and `models/housing/exports/electronics_bay.stl`

- [ ] **Step 1: Write the modeling script**

Create `models/housing/blender_scripts/03_electronics_bay.py`:

```python
import bpy
import sys
sys.path.insert(0, "/Users/neilmedici/Documents/GitHub/OpenRip/models/housing")
import measurements as m

MM = 0.001
CLEARANCE_MM = 0.3
FLOOR_THICKNESS_MM = 1.5
WALL_MM = 2.0

def mm(v):
    return v * MM

def add_pocket(carrier, name, center_x_mm, center_y_mm, l_mm, w_mm, depth_mm, block_h_mm):
    """Cuts a rectangular pocket into `carrier`, centered at (center_x_mm,
    center_y_mm) in world mm, recessed depth_mm from the block's top."""
    cutter_z = mm(block_h_mm) - mm(depth_mm) / 2
    bpy.ops.mesh.primitive_cube_add(size=1, location=(mm(center_x_mm), mm(center_y_mm), cutter_z))
    cutter = bpy.context.object
    cutter.scale = (mm(l_mm), mm(w_mm), mm(depth_mm) + mm(1.0))
    bpy.ops.object.transform_apply(location=False, rotation=False, scale=True)
    mod = carrier.modifiers.new(name=name, type='BOOLEAN')
    mod.operation = 'DIFFERENCE'
    mod.object = cutter
    bpy.context.view_layer.objects.active = carrier
    bpy.ops.object.modifier_apply(modifier=name)
    bpy.data.objects.remove(cutter, do_unlink=True)

# Three pockets side by side along the bay's length: XIAO, battery, switch.
xiao_l = m.XIAO_LENGTH_MM + 2 * CLEARANCE_MM
xiao_w = m.XIAO_WIDTH_MM + 2 * CLEARANCE_MM
xiao_d = m.XIAO_THICKNESS_MM + 0.5

batt_l = m.BATTERY_LENGTH_MM + 2 * CLEARANCE_MM
batt_w = m.BATTERY_WIDTH_MM + 2 * CLEARANCE_MM
batt_d = m.BATTERY_THICKNESS_MM + 0.5

sw_l = m.SWITCH_LENGTH_MM + 2 * CLEARANCE_MM
sw_w = m.SWITCH_WIDTH_MM + 2 * CLEARANCE_MM
sw_d = m.SWITCH_HEIGHT_MM + 0.5

# Lay the three pockets out left-to-right with WALL_MM between each.
bay_w_mm = max(xiao_w, batt_w, sw_w) + 2 * WALL_MM
bay_l_mm = xiao_l + batt_l + sw_l + 4 * WALL_MM
deepest_pocket_mm = max(xiao_d, batt_d, sw_d)
bay_h_mm = deepest_pocket_mm + FLOOR_THICKNESS_MM

x0 = -bay_l_mm / 2 + WALL_MM + xiao_l / 2
x1 = x0 + xiao_l / 2 + WALL_MM + batt_l / 2
x2 = x1 + batt_l / 2 + WALL_MM + sw_l / 2

bpy.ops.mesh.primitive_cube_add(size=1, location=(0, 0, mm(bay_h_mm) / 2))
bay = bpy.context.object
bay.name = "ElectronicsBay"
bay.scale = (mm(bay_l_mm), mm(bay_w_mm), mm(bay_h_mm))
bpy.ops.object.transform_apply(location=False, rotation=False, scale=True)

add_pocket(bay, "XiaoPocket", x0, 0, xiao_l, xiao_w, xiao_d, bay_h_mm)
add_pocket(bay, "BatteryPocket", x1, 0, batt_l, batt_w, batt_d, bay_h_mm)
add_pocket(bay, "SwitchPocket", x2, 0, sw_l, sw_w, sw_d, bay_h_mm)

# USB-C cutout: through the wall at the XIAO pocket's connector edge (the
# -Y wall, assuming the XIAO's USB-C port faces -Y in its pocket).
usbc_x = x0
usbc_y = -bay_w_mm / 2
bpy.ops.mesh.primitive_cube_add(size=1, location=(mm(usbc_x), mm(usbc_y), mm(bay_h_mm) - mm(xiao_d) / 2))
usbc_cutter = bpy.context.object
usbc_cutter.scale = (mm(8.0), mm(WALL_MM) + mm(1.0), mm(3.0))
bpy.ops.object.transform_apply(location=False, rotation=False, scale=True)
mod = bay.modifiers.new(name="UsbcCut", type='BOOLEAN')
mod.operation = 'DIFFERENCE'
mod.object = usbc_cutter
bpy.context.view_layer.objects.active = bay
bpy.ops.object.modifier_apply(modifier="UsbcCut")
bpy.data.objects.remove(usbc_cutter, do_unlink=True)

# Slide-switch actuator slot: through the top face, above the switch pocket.
bpy.ops.mesh.primitive_cube_add(size=1, location=(mm(x2), 0, mm(bay_h_mm)))
sw_cutter = bpy.context.object
sw_cutter.scale = (mm(m.SWITCH_LENGTH_MM), mm(2.0), mm(2.0))
bpy.ops.object.transform_apply(location=False, rotation=False, scale=True)
mod = bay.modifiers.new(name="SwitchSlotCut", type='BOOLEAN')
mod.operation = 'DIFFERENCE'
mod.object = sw_cutter
bpy.context.view_layer.objects.active = bay
bpy.ops.object.modifier_apply(modifier="SwitchSlotCut")
bpy.data.objects.remove(sw_cutter, do_unlink=True)

bpy.ops.wm.save_mainfile()
print("ElectronicsBay bounding box (m):", bay.dimensions)
```

- [ ] **Step 2: Run it through the Blender code-execution tool, then export**

Same pattern as Task 5 Step 2, substituting `ElectronicsBay` / `electronics_bay.stl`.

- [ ] **Step 3: Add the verification entry**

In `models/housing/verify_part.py`, add to the `PARTS` dict:

```python
    "electronics_bay": {
        "path": "models/housing/exports/electronics_bay.stl",
        "min_extents_mm": (
            m.XIAO_LENGTH_MM + m.BATTERY_LENGTH_MM,  # side-by-side pockets
            max(m.XIAO_WIDTH_MM, m.BATTERY_WIDTH_MM, m.SWITCH_WIDTH_MM),
            max(m.XIAO_THICKNESS_MM, m.BATTERY_THICKNESS_MM, m.SWITCH_HEIGHT_MM),
        ),
    },
```

- [ ] **Step 4: Run the verification**

```bash
cd models/housing
python3 verify_part.py electronics_bay
```

Expected: `PASS: ...`.

- [ ] **Step 5: Commit**

```bash
git add models/housing/blender_scripts/03_electronics_bay.py models/housing/verify_part.py models/housing/exports/electronics_bay.stl
git commit -m "Model M1 electronics bay: XIAO, battery, switch pockets + cutouts"
```

---

### Task 7: Model the launcher mounting clip and shell-joining tabs

**Files:**
- Create: `models/housing/blender_scripts/04_mounting_and_joints.py`

**Interfaces:**
- Consumes: `LauncherScan`, `SensorCarrier`, `ElectronicsBay`
- Produces: `SensorCarrier` and `ElectronicsBay` updated in place with mounting-clip geometry and matching snap-fit tabs; re-exported STLs (same filenames as Tasks 5/6 — overwritten).

- [ ] **Step 1: Write the script**

Create `models/housing/blender_scripts/04_mounting_and_joints.py`. This is the one genuinely scan-dependent step the design spec flagged as an open question (exact clip geometry). Implement it as: intersect a thin (2mm) shell offset from `LauncherScan`'s top-face surface directly beneath `SensorCarrier`'s footprint, using Blender's Shrinkwrap modifier to conform a flat plate to the scan surface, then boolean-UNION that conformed plate onto `SensorCarrier`'s underside so it registers against the real contour instead of a flat assumption:

```python
import bpy

carrier = bpy.data.objects["SensorCarrier"]
scan = bpy.data.objects["LauncherScan"]

bpy.ops.mesh.primitive_plane_add(size=0.03, location=carrier.location)
plate = bpy.context.object
plate.name = "RegistrationPlate"
solidify = plate.modifiers.new(name="Solidify", type='SOLIDIFY')
solidify.thickness = 0.002
shrinkwrap = plate.modifiers.new(name="Shrinkwrap", type='SHRINKWRAP')
shrinkwrap.target = scan
shrinkwrap.wrap_method = 'NEAREST_SURFACEPOINT'
bpy.context.view_layer.objects.active = plate
bpy.ops.object.modifier_apply(modifier="Solidify")
bpy.ops.object.modifier_apply(modifier="Shrinkwrap")

union = carrier.modifiers.new(name="RegistrationUnion", type='BOOLEAN')
union.operation = 'UNION'
union.object = plate
bpy.context.view_layer.objects.active = carrier
bpy.ops.object.modifier_apply(modifier="RegistrationUnion")
bpy.data.objects.remove(plate, do_unlink=True)

print("Registration plate conformed and unioned into SensorCarrier.")
bpy.ops.wm.save_mainfile()
```

Snap-fit tabs joining `SensorCarrier` to `ElectronicsBay`: run this immediately after the registration-plate code above, in the same script. It reads both objects' actual `.dimensions` live rather than requiring anyone to copy numbers by hand:

```python
bay = bpy.data.objects["ElectronicsBay"]
carrier = bpy.data.objects["SensorCarrier"]  # already updated above

TAB_WIDTH_M = 0.003
TAB_DEPTH_M = 0.0015

# Tabs are added to ElectronicsBay's face closest to SensorCarrier. This
# assumes the bay sits at +X relative to the carrier — check the Step 3
# viewport screenshot; if they're arranged along Y instead, swap the X
# references below for Y ones before running.
bay_min_x = bay.location.x - bay.dimensions.x / 2
tab_y_positions = [
    bay.location.y - bay.dimensions.y / 4,
    bay.location.y + bay.dimensions.y / 4,
]

for i, y in enumerate(tab_y_positions):
    bpy.ops.mesh.primitive_cube_add(
        size=1, location=(bay_min_x - TAB_DEPTH_M / 2, y, bay.location.z)
    )
    tab = bpy.context.object
    tab.scale = (TAB_DEPTH_M, TAB_WIDTH_M, TAB_WIDTH_M)
    bpy.ops.object.transform_apply(location=False, rotation=False, scale=True)
    union = bay.modifiers.new(name=f"TabUnion_{i}", type='BOOLEAN')
    union.operation = 'UNION'
    union.object = tab
    bpy.context.view_layer.objects.active = bay
    bpy.ops.object.modifier_apply(modifier=f"TabUnion_{i}")
    bpy.data.objects.remove(tab, do_unlink=True)

# Matching slots cut into SensorCarrier at the same Y positions, sized
# 20% larger than the tabs for a snap-fit (not press-fit) clearance.
carrier_max_x = carrier.location.x + carrier.dimensions.x / 2
for i, y in enumerate(tab_y_positions):
    bpy.ops.mesh.primitive_cube_add(
        size=1, location=(carrier_max_x + TAB_DEPTH_M / 2, y, bay.location.z)
    )
    slot = bpy.context.object
    slot.scale = (TAB_DEPTH_M * 1.2, TAB_WIDTH_M * 1.2, TAB_WIDTH_M * 1.2)
    bpy.ops.object.transform_apply(location=False, rotation=False, scale=True)
    diff = carrier.modifiers.new(name=f"TabSlot_{i}", type='BOOLEAN')
    diff.operation = 'DIFFERENCE'
    diff.object = slot
    bpy.context.view_layer.objects.active = carrier
    bpy.ops.object.modifier_apply(modifier=f"TabSlot_{i}")
    bpy.data.objects.remove(slot, do_unlink=True)

bpy.ops.wm.save_mainfile()
print("Snap tabs added:", [t for t in bay.modifiers.keys() if t.startswith("TabUnion")])
```

- [ ] **Step 2: Run it through the Blender code-execution tool**

- [ ] **Step 3: Visual verification**

Take a viewport screenshot showing `SensorCarrier` sitting on `LauncherScan`. Expected: the carrier's underside visibly follows the scan's surface contour rather than floating above it or clipping through it. If it clips through or floats, the `Shrinkwrap` target offset needs adjusting (add a small positive offset in the modifier before applying).

- [ ] **Step 4: Re-export both parts**

Same export pattern as Task 5 Step 2 / Task 6 Step 2, overwriting `sensor_carrier.stl` and `electronics_bay.stl`.

- [ ] **Step 5: Re-run both verifications**

```bash
cd models/housing
python3 verify_part.py sensor_carrier
python3 verify_part.py electronics_bay
```

Expected: both `PASS`.

- [ ] **Step 6: Commit**

```bash
git add models/housing/blender_scripts/04_mounting_and_joints.py models/housing/exports/sensor_carrier.stl models/housing/exports/electronics_bay.stl
git commit -m "Add scan-conformed mounting registration and shell-joining tabs"
```

---

### Task 8: Export STEP and save the Blender source

**Files:**
- Create: `models/housing/freecad_convert.py`
- Create: `models/housing/exports/sensor_carrier.step`
- Create: `models/housing/exports/electronics_bay.step`

**Interfaces:**
- Consumes: `models/housing/exports/sensor_carrier.stl`, `models/housing/exports/electronics_bay.stl`
- Produces: `.step` counterparts of both — the actual `SPEC.md` §6 STEP deliverable.

- [ ] **Step 1: Write the FreeCAD conversion script**

Create `models/housing/freecad_convert.py`:

```python
"""
Converts housing STL exports to STEP using FreeCAD's headless Python API.
Run with: freecad --console models/housing/freecad_convert.py
(or the full path to FreeCAD's bundled Python if `freecad` isn't on PATH)
"""
import FreeCAD
import Part
import Mesh
import os

PARTS = ["sensor_carrier", "electronics_bay"]
BASE = "/Users/neilmedici/Documents/GitHub/OpenRip/models/housing/exports"

for part in PARTS:
    stl_path = os.path.join(BASE, f"{part}.stl")
    step_path = os.path.join(BASE, f"{part}.step")

    doc = FreeCAD.newDocument(part)
    mesh_obj = doc.addObject("Mesh::Feature", "Mesh")
    mesh_obj.Mesh = Mesh.Mesh(stl_path)

    shape = Part.Shape()
    shape.makeShapeFromMesh(mesh_obj.Mesh.Topology, 0.05)  # 0.05mm sewing tolerance
    solid = Part.makeSolid(shape) if shape.Faces else shape

    part_obj = doc.addObject("Part::Feature", "Solid")
    part_obj.Shape = solid
    doc.recompute()

    Part.export([part_obj], step_path)
    print(f"Converted {stl_path} -> {step_path}")
    FreeCAD.closeDocument(doc.Name)
```

- [ ] **Step 2: Run the conversion**

```bash
freecad --console models/housing/freecad_convert.py
```

Expected: two `Converted ... -> ...step` lines, and both `.step` files exist under `models/housing/exports/`.

- [ ] **Step 3: Verify the STEP files load and have solid geometry**

```bash
python3 -c "
import FreeCAD
for name in ['sensor_carrier', 'electronics_bay']:
    doc = FreeCAD.newDocument(name)
    doc.load(f'models/housing/exports/{name}.step')
    solids = [o for o in doc.Objects if hasattr(o, 'Shape') and o.Shape.Solids]
    print(name, 'solids:', sum(len(o.Shape.Solids) for o in solids))
"
```

Expected: `sensor_carrier solids: 1` and `electronics_bay solids: 1` (a solid, not just a surface shell — if 0, the sewing tolerance in Step 1 needs loosening, e.g. 0.1mm instead of 0.05mm).

- [ ] **Step 4: Commit**

```bash
git add models/housing/freecad_convert.py models/housing/exports/sensor_carrier.step models/housing/exports/electronics_bay.step models/housing/openrip-housing.blend
git commit -m "Convert M1 housing parts to STEP; save Blender source"
```

---

### Task 9: First print and physical fit test (human action)

**Files:**
- Create: `models/housing/fit-test-log.md`

**Interfaces:**
- Consumes: `models/housing/exports/sensor_carrier.stl`, `models/housing/exports/electronics_bay.stl`
- Produces: `models/housing/fit-test-log.md` — a running log of print attempts and fit issues, which feeds back into `measurements.py` and the Blender scripts for the next iteration (loop back to Task 5/6/7 as needed).

- [ ] **Step 1 (human action): Slice and print the sensor carrier first**

Per the design spec's acceptance criteria: print `sensor_carrier.stl` alone first (smaller, most fit-critical) before committing filament/time to the full electronics bay.

- [ ] **Step 2 (human action): Test-fit against the real launcher**

Check each item from the design spec's acceptance criteria:
- Clips onto the top face snugly, no wobble, removes cleanly without tools or residue
- Doesn't interfere with normal winding, bey-seating, or grip
- Sensor module sits at the right standoff over the window (re-run the M0b raw-mode ADC check with the module in the printed pocket — same procedure as `docs/sensor-characterization.md`)
- Switch carriage calibration passes (`ARMED`/`IDLE` per `docs/build-guide.md`), and the lever doesn't resist bey seating

- [ ] **Step 3: Log the results**

Create `models/housing/fit-test-log.md`:

```markdown
# M1 Housing Fit-Test Log

## Attempt 1 — <date>

- Printer/settings: <printer, nozzle, layer height>
- Registration fit: <pass/fail + notes>
- Sensor standoff / raw-mode signal: <pass/fail + notes>
- Switch carriage calibration: <pass/fail + notes>
- Adjustments needed: <e.g. "pocket 0.3mm too tight, bump CLEARANCE_MM to 0.4">
```

Fill in the actual attempt's results.

- [ ] **Step 4: If adjustments are needed, loop**

Update the relevant constants in `measurements.py` or the `CLEARANCE_MM`/slot dimensions in the Task 5/6/7 scripts, re-run those tasks' steps, reprint, and log a new attempt entry. Repeat until all four checklist items in Step 2 pass.

- [ ] **Step 5: Once all criteria pass, print the electronics bay and do a full end-to-end test**

Print `electronics_bay.stl`, assemble everything (XIAO, battery, switch, sensor module, microswitch), snap the two halves together, mount on the launcher, and do one real rip-cord launch. Confirm the launch report matches the bench validation (peak RPM in the expected 5,000–12,000 range, plausible pulse count) — same acceptance check as the design spec.

- [ ] **Step 6: Commit the final fit-test log**

```bash
git add models/housing/fit-test-log.md
git commit -m "Log M1 housing fit-test results; mark acceptance criteria met"
```

---

## Self-Review Notes

- **Spec coverage:** every design-spec section has a task — pipeline (Tasks 2-8), components (Tasks 5-7), repo conventions (Task 1), acceptance criteria (Task 9). The two spec "open questions" (exact clip geometry, sensor standoff) are resolved by Task 7's scan-conformed shrinkwrap approach and Task 3's direct measurement, respectively — the third (Blender→STEP path) is resolved by Task 8's FreeCAD bridge.
- **Type/name consistency:** `SensorCarrier`, `ElectronicsBay`, `LauncherScan`, `WindowCenter`, `PlungerCenter` are used identically across Tasks 4-8; `measurements.py`'s constant names are defined once in Task 3 and referenced verbatim in Tasks 5-6.
- **Known gap, called out rather than hidden:** Task 2's exact MCP tool names can't be pinned down until the addon is actually installed (third-party project, version-dependent) — Step 3 has the engineer discover them via `ToolSearch` rather than guessing, and every later task's "Blender code-execution tool" phrase refers back to that discovery.

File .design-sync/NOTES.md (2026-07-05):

# design-sync notes — OpenRip

- The DS package lives at `design/` (`@openrip/design`), created 2026-07-04
  specifically to codify the shipped vanilla app's look (`app/style.css` is
  the visual source of truth the DS mirrors — keep them in agreement).
- No dist entry in node_modules (own-repo): always pass
  `--entry ./design/dist/index.js` and `--node-modules design/node_modules`.
- `dist/styles.css` is built self-contained: the package build **prepends**
  `src/tokens.css` (same-package tokens can't ship via `tokensGlob`, which
  requires a separate `tokensPkg` in node_modules). Don't re-add an
  `@import "./tokens.css"` to `src/styles.css` — it broke the bundle closure
  once already ([CSS_IMPORT_MISSING]).
- Fonts are Google-Fonts remote (`@import` at top of tokens.css) →
  `[FONT_REMOTE]` info line is expected, not a problem.
- The repo root `.gitignore` has a global `dist/` rule (predates the DS), so
  `design/dist/` is untracked — run `npm run build --prefix design` before
  any converter run.
- `overrides.StatTile.cardMode = column`: the StatsGrid story is wider than
  a grid cell ([GRID_OVERFLOW] fix, presentation-only).
- Components assume a LIGHT paper ground (identity v3, 2026-07-04:
  "open=rip" light editorial / ray=out zine — replaced the dark looks);
  all authored previews wrap stories in a `var(--or-bg)` container. Do the
  same for any new preview. The wrappers' inline fallback `#0a0b0d` is stale
  (never used while the token resolves) — harmless.

## Known render warns

(none — 8/8 clean, no triaged warns)

## Re-sync risks

- The DS mirrors `app/style.css` by hand — if the app's CSS evolves without
  touching `design/`, the sync happily re-verifies a stale look. Check the
  two agree when the app has changed.
- Google Fonts loads at runtime in previews; a network-less environment
  will render fallback fonts and could fail grading spuriously.
- Playwright chromium was installed to the default cache
  (`~/Library/Caches/ms-playwright`, headless-shell v1228) — a fresh machine
  needs `npx playwright install chromium` from `.ds-sync/`.
- Nothing was partially verified: all 8 components authored + graded good.

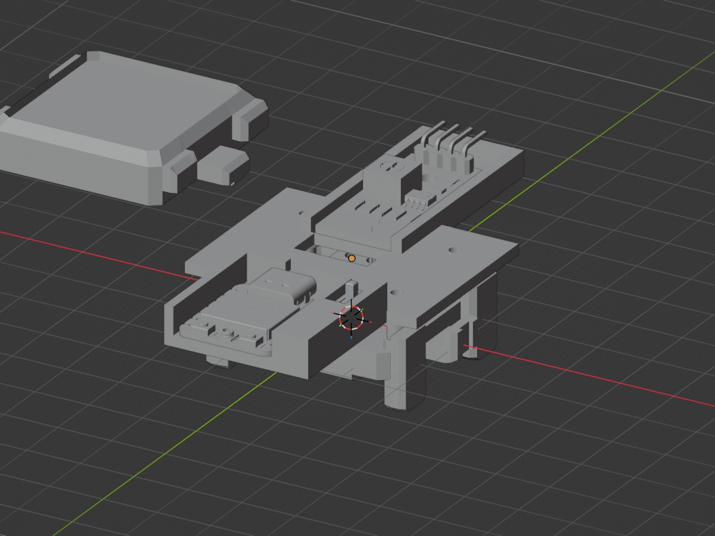
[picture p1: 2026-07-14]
models/ref/deck-screenshots/final_iso2.png

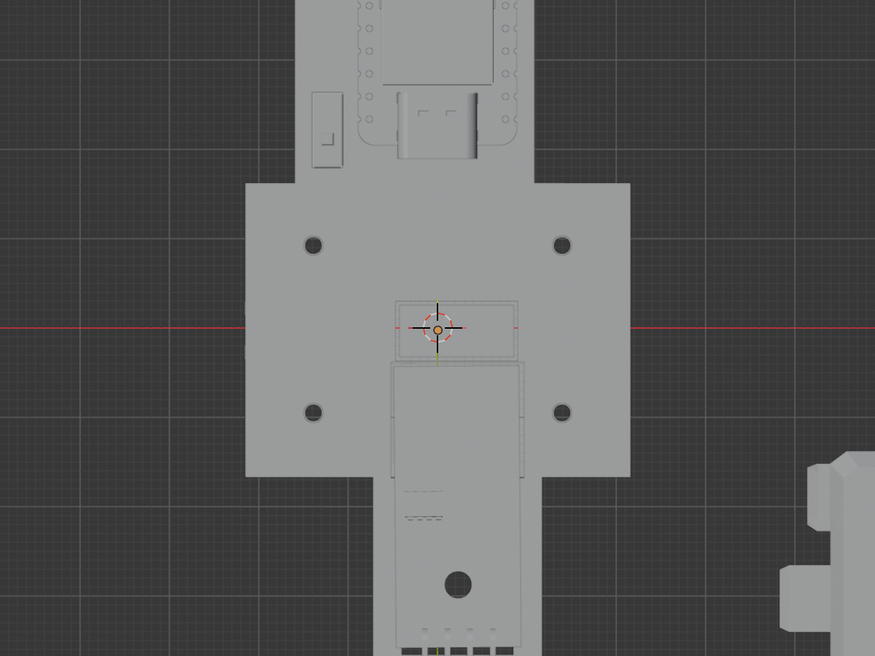
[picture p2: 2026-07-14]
models/ref/deck-screenshots/final_top.png

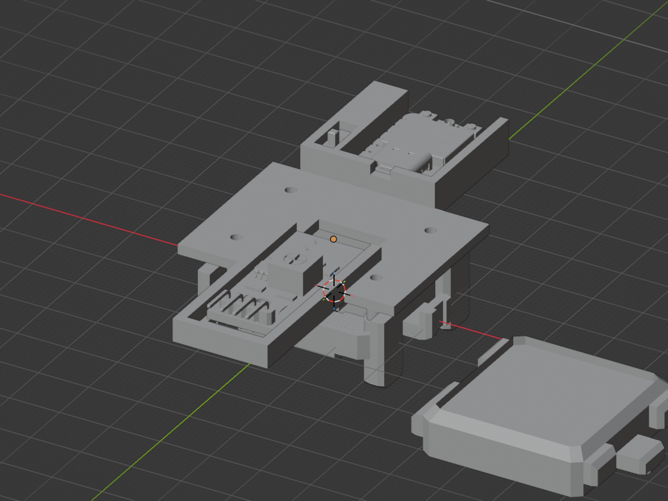
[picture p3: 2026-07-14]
models/ref/deck-screenshots/final_iso.png

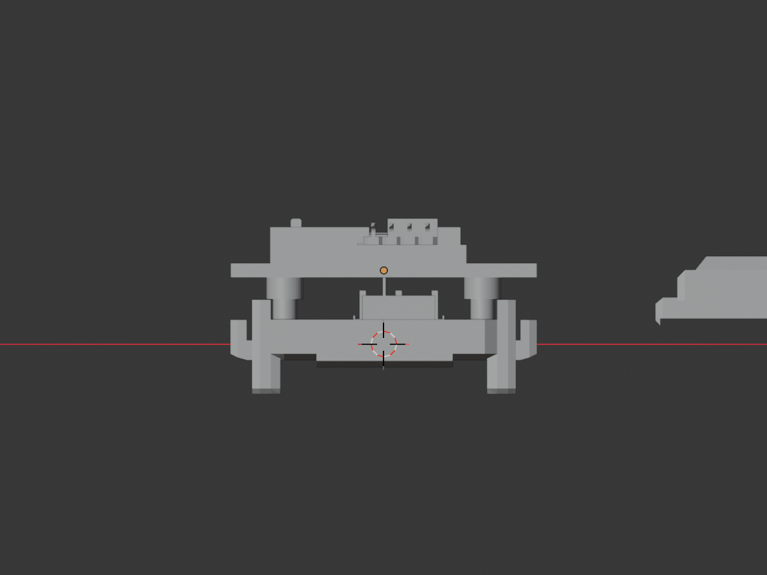
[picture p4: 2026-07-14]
models/ref/deck-screenshots/final_front.png

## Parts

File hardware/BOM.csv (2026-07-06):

ref | part | component | qty | est_cost_usd | supplier | link | notes
MCU1 | MCU | Seeed XIAO ESP32-C3 | 1 | 4.99 | Seeed Studio | https://www.seeedstudio.com/Seeed-XIAO-ESP32C3-p-5431.html | 3-pack $13.49: https://www.seeedstudio.com/Seeed-Studio-XIAO-ESP32C3-3PCS-p-5920.html — also on Amazon (B0B94JZ2YF). Onboard LiPo charging + BLE
OS1 | Spin sensor | TCRT5000 IR reflective sensor (Vishay) | 3 | 1.50 | DigiKey | https://www.digikey.com/en/products/detail/vishay-semiconductor-opto-division/TCRT5000/1681167 | Primary. Reads the winder's factory encoder disc through the ~5x5mm top-face window; peak sensitivity ~2.5mm matches the ~3mm recess. Package is wider than the window — domes partially overhang (see wiring.md). Buy bare sensors, not LM393 comparator modules — the firmware wants the raw analog signal
OS2 | Spin sensor (alt) | ITR8307/TR8 IR reflective sensor (Everlight) | 3 | 0.60 | DigiKey | https://www.digikey.com/en/products/detail/everlight-electronics-co-ltd/ITR8307-TR8/2693862 | Documented fallback if the TCRT5000's signal swing off the encoder disc is poor. Compact SMD package fits inside the window footprint. Base ITR8307 part is out of stock at DigiKey; the /TR8 variant ships
R1 | Resistor | 100Ω 1/4W (IR emitter current limit) | 3 | 0.10 | any |  | (3.3V − ~1.25V Vf) / 100Ω ≈ 20mA emitter current
R2 | Resistor | 10kΩ 1/4W (phototransistor pull-up) | 3 | 0.10 | any |  | Collector to 3V3; reflection pulls the ADC reading low
SW2 | Bey presence | Omron D2F-01FL ultra-subminiature hinge lever microswitch (SPDT) | 2 | 2.00 | DigiKey | https://www.digikey.com/en/products/detail/omron-electronics-inc-emc-div/D2F-01FL/368431 | REQUIREMENT: subminiature lever, <0.5mm differential travel, <0.5N actuation force (D2F-01FL class) — the plunger only rises ~1mm above flush, so sloppy-travel switches can't discriminate seated vs released. Mounts on the housing's adjustable carriage (slot + M2 screw), calibrated once per build. COM→GPIO (internal pull-up), NO→GND
FS1 | Fastener | M2 x 6mm screw + nut (switch carriage) | 2 | 0.20 | any |  | Locks the switch carriage after calibration; heat-set insert works too
BT1 | Battery (M1) | 401030 LiPo ~100mAh 3.7V | 1 | 8.00 | Amazon | https://www.amazon.com/HAFHNRUY-401030-Lithium-Rechargeable-Battery/dp/B0F9DYDHVX | M1 — skip for M0 breadboard (USB-C powers it). XIAO has bare BAT solder pads, no connector: buy wired cells and VERIFY POLARITY with a multimeter before soldering — lead colors from these vendors are not trustworthy. 401230 (4x12x30mm) also fits and is easier to find with protection PCM (e.g. B0FT3GG4ZL)
SW1 | Switch (M1) | SS12D00 SPDT mini slide switch 10-pack | 1 | 6.00 | Amazon | https://www.amazon.com/Slide-Switch-Mini-SPDT-Breadboard/dp/B0B39NMGHJ | M1 — 2.54mm pitch, breadboard-friendly. Adafruit 805 is the name-brand equivalent
H1 | Housing (M1) | PLA filament (top-face mount shell) | 1 | 0.30 | any |  | Models land in /models after M0b validates the optical signal
BB1 | Prototyping | Breadboard + M-M jumper wires | 1 | 8.00 | Amazon | https://www.amazon.com/s?k=breadboard+jumper+wire+kit | Any 400-point board + jumper kit; skip if you have them

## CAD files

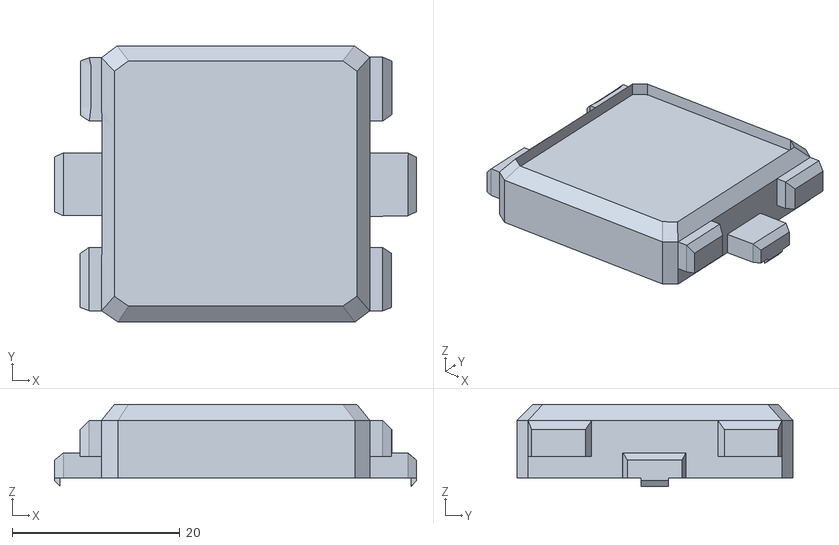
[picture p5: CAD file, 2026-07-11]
models/BP_gear_Medal_Top.stl
43.2 x 32.9 x 9.79

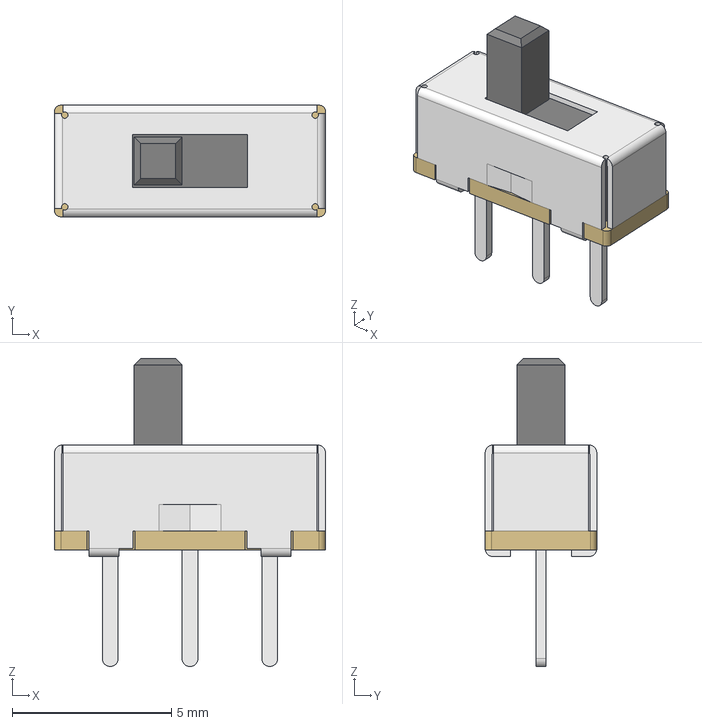
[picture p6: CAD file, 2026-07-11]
models/ref/SPDT slide switch SS12D00.step
8.50 x 3.50 x 9.66 mm

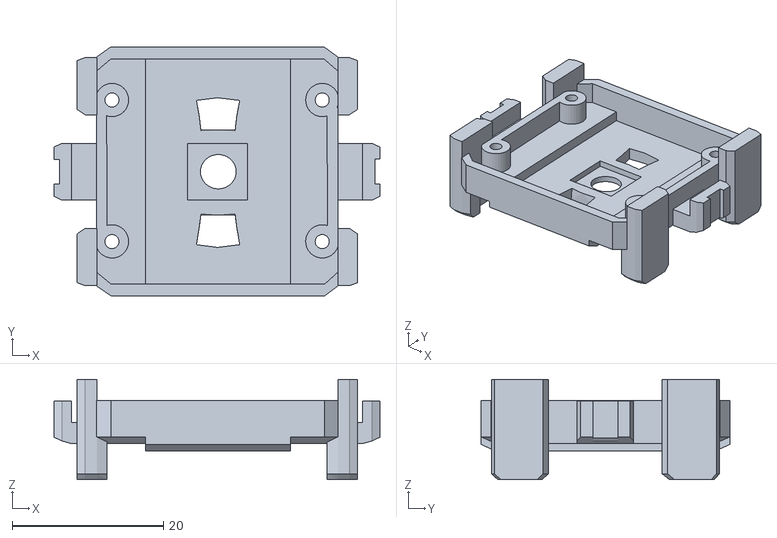
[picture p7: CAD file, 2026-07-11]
models/BP_gear_port.stl
43.1 x 33.0 x 13.3

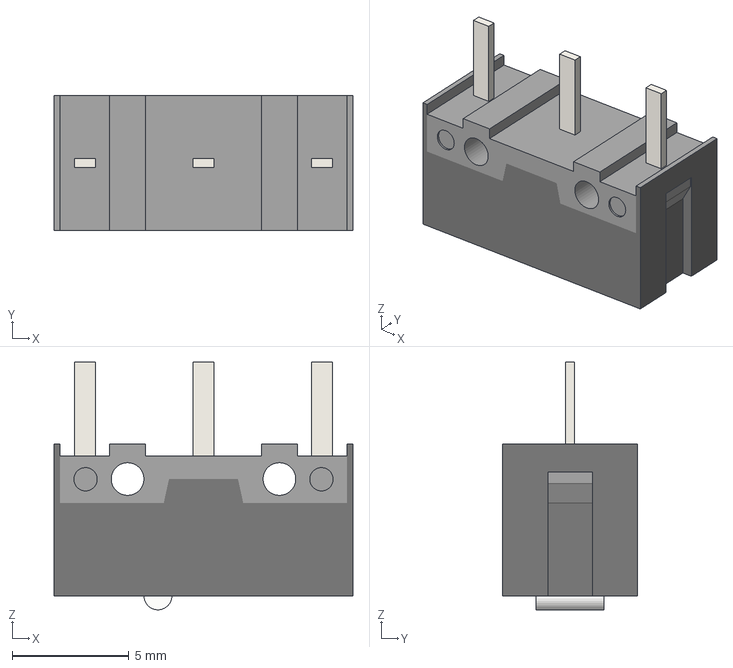
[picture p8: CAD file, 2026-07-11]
models/ref/Omron_D2FC.3mf
12.8 x 5.80 x 10.6 mm

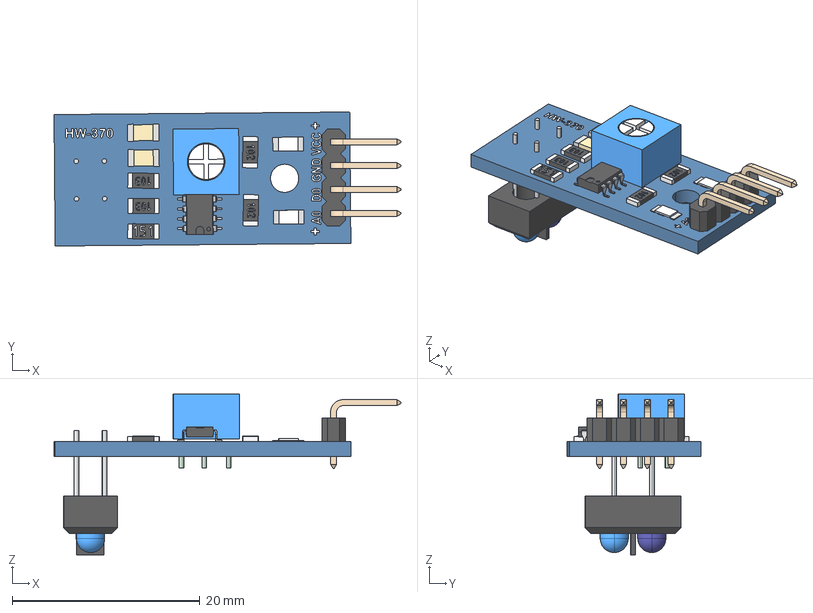
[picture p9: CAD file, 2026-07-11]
models/ref/TCRT5000.stp
37.0 x 14.3 x 17.1 mm
TCRT5000
leds Geometry
pin
IC_smd_8
smd_10k Geometry x 2
cover x 2
smd_150 Geometry
cover2
Surf Geometry x 2
cover3 x 2
LED_SMD x 2
smd_1k Geometry x 2
cover4 x 2
pot Geometry
pin2
leds2 Geometry
pins
Board Geometry
TXT
4PinsOut Geometry
pin3

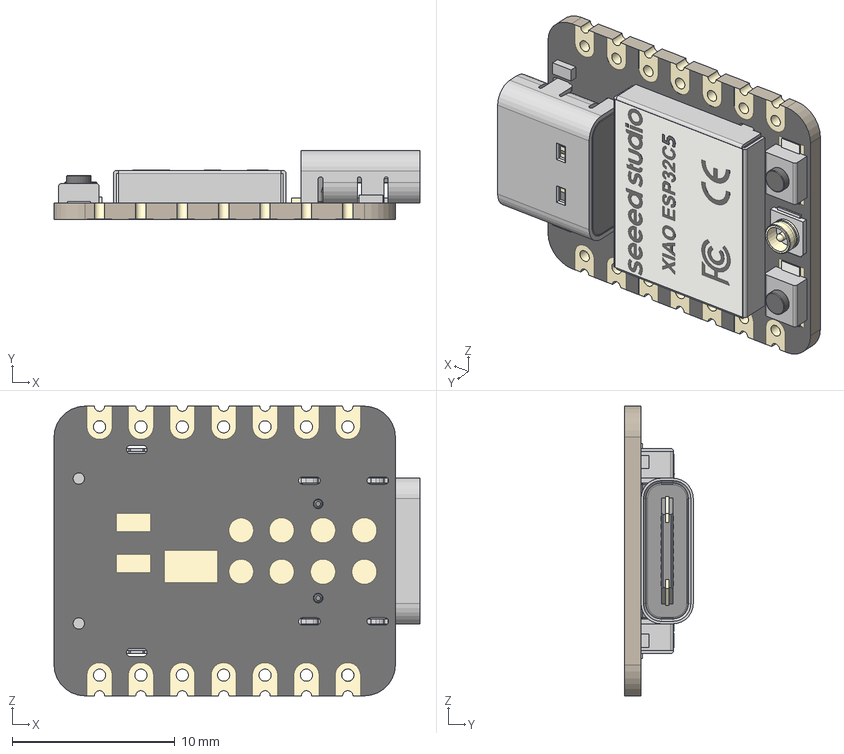
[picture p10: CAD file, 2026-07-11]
models/ref/Seeed Studio XIAO ESP32-C5.step
22.5 x 4.21 x 17.8 mm
BOSS-EXTRUDE14_8_
BOSS-EXTRUDE7_4_
BOSS-EXTRUDE7_3_
BOSS-EXTRUDE14_4_
BOSS-EXTRUDE14_2_
BOSS-EXTRUDE14_11_
BOSS-EXTRUDE7_7_
BOSS-EXTRUDE14_9_
BOSS-EXTRUDE14_3_
BOSS-EXTRUDE14_7_
MIRROR2
BOSS-EXTRUDE14_5_
BOSS-EXTRUDE14_12_
BOSS-EXTRUDE7_8_
BOSS-EXTRUDE7_1_
BOSS-EXTRUDE14_10_
BOSS-EXTRUDE7_9_
BOSS-EXTRUDE14_6_
BOSS-EXTRUDE14_1_
BOSS-EXTRUDE7_6_
BOSS-EXTRUDE7_2_
CUT-EXTRUDE5
BOSS-EXTRUDE7_5_
U.FL Connector v1
Button (1) x 2
Shield

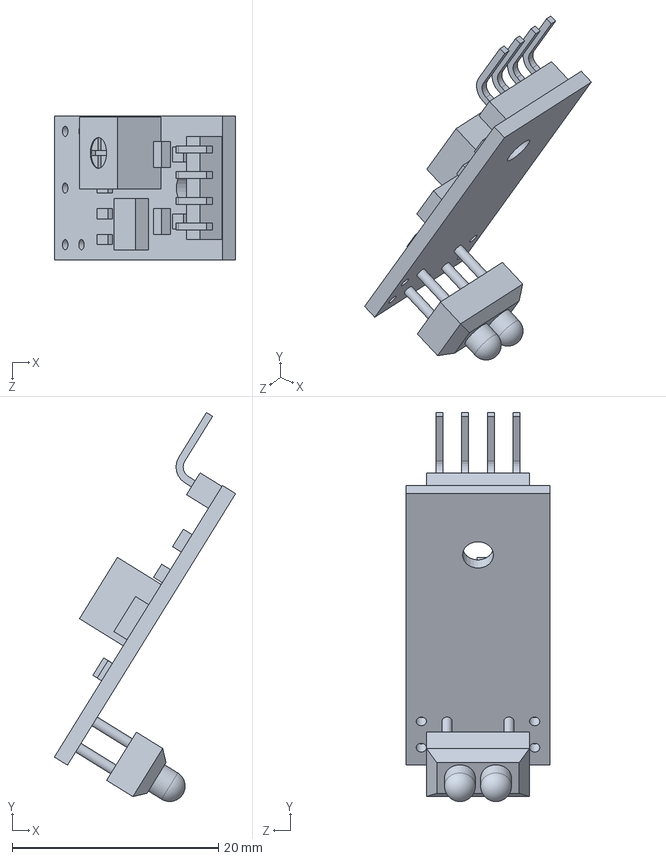
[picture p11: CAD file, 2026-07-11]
models/ref/TCRT5000mod.SLDPRT
17.6 x 37.8 x 14.0 mm

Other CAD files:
models/ref/stl/slide_switch_ss12d00.stl
models/OpenRip_housing_wip.blend
models/ref/stl/omron_d2fc.stl

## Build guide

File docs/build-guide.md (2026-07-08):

# OpenRip Build Guide

> Skeleton — sections fill in as each milestone lands. SPEC.md §8 is the
> source of truth for milestone scope.

## M0a — Mount characterization

<!-- Photograph the launcher's top-face encoder window, identify the rotating surface
     and its optical features, measure working distance. Procedure:
     /docs/sensor-characterization.md. Gates M0b. -->

## M0b — Sensor proof (breadboard) ✅ complete

Parts and wiring: `hardware/wiring.md`. Full procedure and measured
findings: `docs/sensor-characterization.md`.

Short version: flash the `m0-serial` env, `pio device monitor`, send `r`
for raw ADC mode, hand-crank the winder to capture real white/black
levels, set `SENSOR_THRESH_LOW`/`HIGH` in `firmware/include/config.h`
from what you see, reflash, and confirm the pulse count matches crank
revolutions. Wire the plunger microswitch (COM → D3, NO → GND) to unlock
the presence-gated launch report — that gives an exact pulse/RPM readout
instead of hand-counting raw ADC lines.

Go/no-go gate — **passed**: clean two-level pulse train off a real
launcher, launch RPM readings landing in the expected 5,000–12,000 range.

## M1 — v0.1 device

<!-- Soldering, battery + switch, printed housing assembly (see /models),
     BLE launch records. -->

### Switch carriage calibration (once per build)

The plunger only rises ~1mm above flush, so the presence switch sits on an
adjustable carriage (slot + M2 screw) instead of a fixed pocket.

1. Mount the housing on the launcher, carriage screw loose.
2. With a bey **seated**: slide the carriage toward the plunger until the
   switch clicks (serial shows `# state: ARMED`).
3. Remove the bey: the switch must release (`# state: IDLE`). If it stays
   clicked, back the carriage off a hair and repeat.
4. Tighten the M2 screw and re-check both states, plus seating feel — the
   lever must not resist the bey clicking in.

## M2 — App

<!-- Connecting from the Web Bluetooth app, launch history, CSV export. -->

## M3 — Public v0.1

<!-- Flashing from the browser with ESP Web Tools; companion video.
     Flash page stub: /app/flash/ (index.html + manifest.json). Each release
     needs a single merged binary at offset 0, built from the pio output:
       esptool.py --chip esp32c3 merge_bin -o openrip-merged.bin \
         0x0    firmware/.pio/build/m0-serial/bootloader.bin \
         0x8000 firmware/.pio/build/m0-serial/partitions.bin \
         0x10000 firmware/.pio/build/m0-serial/firmware.bin
     Attach it to the GitHub Release and point manifest.json at it. -->

## M4 — v0.2 IMU

<!-- IMU install, launch angle, calibration (see calibration.md),
     smoothness scoring. -->

## M5 — Custom PCB (optional)

<!-- Small-batch PCB path. -->

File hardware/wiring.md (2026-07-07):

# Wiring — TCRT5000 Optical Sensor → XIAO ESP32-C3

M0b breadboard hookup. The firmware samples the TCRT5000's phototransistor
on an **ADC pin** (`PIN_SENSOR` = A1 = GPIO3, set in
`firmware/include/config.h`) and converts reflectivity changes into pulses
with a software Schmitt trigger.

**Target (confirmed at M0a):** the winder launcher's factory optical
encoder — a black/white two-segment disc visible through a ~5×5mm clear
window on the launcher's top face, disc surface ~3mm below the window. The
launcher is never modified; the sensor just looks through the window the
official device uses.

## TCRT5000 hookup

The package has two domes: an IR LED (blue-tinted) and a phototransistor
(black). Datasheet: Vishay TCRT5000.

| TCRT5000 pin | Via | XIAO ESP32-C3 |
|---|---|---|
| LED anode (A) | 100Ω resistor | 3V3 |
| LED cathode (K) | — | GND |
| Phototransistor collector (C) | 10kΩ pull-up to 3V3, tap to pin | A1 (GPIO3) |
| Phototransistor emitter (E) | — | GND |

```
IR LED side
  3V3 ──[ 100Ω ]──────── A   (LED anode)
  GND ──────────────────  K   (LED cathode)

Phototransistor side (pull-up divider — the node between the
10kΩ and the collector is what A1 actually reads)
  3V3 ──[ 10kΩ ]──┬────── A1 (GPIO3)   → XIAO ADC input
                  └────── C   (collector)
  GND ──────────────────  E   (emitter)
```

- **Emitter current:** (3.3V − ~1.25V Vf) / 100Ω ≈ 20mA — comfortable for
  the TCRT5000's LED.
- **Signal sense:** more IR reflected (white segment in view) → more
  phototransistor current → the pulled-up collector reads **lower**. The
  firmware registers a pulse on the falling crossing (`SENSOR_THRESH_LOW`)
  and re-arms on the rising one (`SENSOR_THRESH_HIGH`).
- **Distance:** peak sensitivity is ~2.5mm — a near-perfect match for the
  disc sitting ~3mm below the window with the sensor face flush against it.

### Package fit warning

The TCRT5000 body (~10.2 × 5.8mm) is **wider than the 5×5mm window** — the
emitter/detector domes partially overhang the window edges. On the
breadboard, center the package over the window as best you can and expect
some signal loss from the overhang. If the white/black swing in raw mode is
too small to threshold cleanly, the documented fallback is the
**ITR8307** (compact SMD, fits inside the window footprint) — same wiring
topology, same firmware.

## Bey-presence microswitch (plunger)

Next to the encoder window the winder launcher has a **spring plunger**
that sits below flush when empty, rises **~1mm above flush** when a bey is
locked in, and drops the moment the bey releases. A subminiature lever
microswitch (Omron D2F-01FL class: SPDT, <0.5mm differential travel,
<0.5N actuation) rides it and gives the firmware a bey-presence input —
this is what gates launch detection and timestamps the release.

| Microswitch pin | XIAO ESP32-C3 |
|---|---|
| COM | D3 (GPIO5) |
| NO (normally open) | GND |
| NC | unused |

```
D2F-01FL (SPDT)
  D3 (GPIO5) ──────────── COM   → XIAO input, INPUT_PULLUP
  GND ──────────────────── NO
                           NC   (unused — leave unconnected)
```

- The firmware uses `INPUT_PULLUP`: bey locked → plunger up → lever
  pressed → NO closes → the pin reads **LOW = bey present**. Debounce is
  in firmware (~5ms, `PLUNGER_DEBOUNCE_MS`).
- **Force and travel budgets matter:** the lever must actuate well below
  the plunger's spring force (never prevent a bey from seating), and with
  only ~1mm of plunger travel the switch needs <0.5mm differential travel
  to discriminate seated vs released. In the M1 housing the switch sits on
  an adjustable carriage (slot + M2 screw) calibrated once per build — see
  docs/build-guide.md.
- On the breadboard, tape/jig the switch so the lever just kisses the
  plunger at its raised height; verify with the serial state prints
  (insert bey → `ARMED`, remove → `IDLE`).

## Characterizing the signal (M0b)

1. Flash and open the monitor: `pio run -t upload && pio device monitor`
2. Send `r` to toggle **raw mode** — the firmware streams `micros,adc`
   lines at max serial rate.
3. **Hand-crank the winder slowly** and watch the two-level signal: white
   segment = low readings, black = high. Set `SENSOR_THRESH_LOW` just above
   the white level, `SENSOR_THRESH_HIGH` just below the black level, with
   the noise band inside the gap.
4. Full procedure and M0a findings: `docs/sensor-characterization.md`.

## Notes

- All sensing tunables live in `firmware/include/config.h` (`PIN_SENSOR`,
  `SENSOR_THRESH_LOW/HIGH`, `PIN_PLUNGER`, `PLUNGER_DEBOUNCE_MS`,
  `PULSES_PER_REV`, `GEAR_RATIO`, `MIN_PULSE_INTERVAL_US`).
- The encoder disc is mounted on the hook shaft (confirmed by teardown) —
  the window reads hook RPM directly (`GEAR_RATIO` = 1.0).
- Ambient IR (sunlight, incandescent) shifts the baseline — characterize
  indoors; the M1 housing shrouds the sensor.
- Battery (401030 LiPo) and slide switch wiring lands with M1; for M0 run
  from USB-C.

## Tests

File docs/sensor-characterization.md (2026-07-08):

# Sensor Characterization

## M0a — Mount characterization ✅ FULLY COMPLETE (2026-07, incl. gearing teardown)

**Finding: the winder launcher has a factory optical encoder.** Sensing is
confirmed viable with zero modification — we read the same surface the
official device reads.

- **What's there:** a black/white **two-segment encoder disc**, visible
  through a **~5×5mm clear window** on the launcher's **top face**.
- **Working distance:** disc surface sits **~3mm below the window** — right
  at the TCRT5000's ~2.5mm sensitivity peak with the sensor face flush to
  the window.
- **Pulses per revolution:** two segments → **1 dark/light cycle per
  encoder revolution** (`PULSES_PER_REV 1` in config.h).
- **Gearing (confirmed by teardown):** the encoder disc is mounted
  directly on the **hook shaft** (16T gear), downstream of the gear
  train — the window reads **hook RPM directly**. `GEAR_RATIO = 1.0`
  confirmed; the constant remains in config.h for potential future
  launcher variants.
- **Remaining signal risk (low):** IR contrast between the *translucent*
  white segment and the black segment at the TCRT5000's wavelength. The
  disc was designed for the official sensor's optics, not ours — M0b
  measures the actual swing.
- **Mechanical note:** the TCRT5000 package is wider than the window; the
  domes partially overhang the opening (see hardware/wiring.md). ITR8307
  is the documented fallback if the swing is poor.

## M0b — Signal proof ✅ complete (2026-07)

1. Breadboard per `hardware/wiring.md`: sensor flush over the window,
   centered, AND the plunger microswitch lever positioned over the spring
   plunger next to the window (tape/jig is fine at this stage).
2. **Verify the plunger state machine first** (no spinning needed). Watch
   the serial monitor's `# state:` lines:
   - lock a bey in → plunger rises → `# state: ARMED`
   - pull the bey back out without launching → `# state: IDLE`
   - repeat a few times; transitions must be clean single edges (no
     chatter — if you see bouncing, raise `PLUNGER_DEBOUNCE_MS`).
   - confirm bey seating feels identical with the switch in place — the
     lever must not fight the plunger.
3. `pio device monitor`, send `r` → raw mode streams `micros,adc` lines.
4. **Hand-crank the winder slowly** (bey locked in, so pulses register).
   Verify a clean two-level signal: white segment = low ADC (more
   reflection), black = high. Capture a few revolutions and save the dump
   under `docs/captures/`.
5. From the capture, set in `firmware/include/config.h`:
   - `SENSOR_THRESH_LOW` just above the white level
   - `SENSOR_THRESH_HIGH` just below the black level
   - (noise band must fit inside the gap — widen it if crossings chatter)
6. Rebuild, hand-crank again in normal mode: pulse count should match
   crank revolutions exactly. Chase any mismatch before step 7.
7. **Live launches.** Watch for `# state: RIPPING` then a launch summary
   whose `end trigger` says **release edge** — a "pulse timeout (fallback)"
   trigger on a real launch means the switch missed the release; fix the
   lever geometry. Readings are hook RPM directly — sanity range
   5,000–12,000. Both peak and release RPM should report, with release a
   bit below peak.

## Findings log

- **Hand-crank capture (breadboard, IR sensor module with onboard LM393
  comparator — AO output wired to XIAO D1/A1, no discrete resistors
  needed):**
  - Quiet baseline: ~190–230 ADC counts, low noise (±20ish).
  - Rotation peaks: 600–2400+ depending on hand-crank speed; weakest
    observed peak ~600.
  - Clean, monotonic edges, spaced ~300–380ms apart during a slow steady
    hand-crank (~3 rev/s).
  - Chosen thresholds: `SENSOR_THRESH_LOW 400`, `SENSOR_THRESH_HIGH 550` —
    clears the baseline noise floor and still reliably re-arms on the
    weakest observed peaks. (Prior defaults of 1600/2400 would have missed
    re-arming on weak cranks entirely.)
- **Plunger microswitch:** wired (COM → D3, NO → GND) and validated —
  `IDLE`/`ARMED`/`RIPPING` states transition cleanly. Pin ID note: on this
  switch only **C** (=COM) and **NC** are silkscreened; the unlabeled
  third pin is **NO**.
- **First real launch reports** (bench test, no housing yet — switch
  manually held/released by hand instead of tracking the real plunger):
  - Peak RPM 6746 and 6654 — both inside the expected 5,000–12,000
    hook-RPM range. Confirms the sensor and `GEAR_RATIO` math end-to-end.
  - All three test launches ended via `pulse timeout (fallback)` rather
    than `release edge` — expected here, not a defect: release RPM was far
    below peak RPM in each (bey spinning down while still seated, not
    physically ejected). Getting a real release-edge trigger needs the
    switch tracking the actual plunger, which is genuinely fiddly at
    breadboard scale given only ~1mm of travel — this is exactly what M1's
    adjustable carriage (build-guide.md) is for.
- **Go/no-go: PASSED.** Clean two-level pulse train confirmed off a real
  launcher, with plausible RPM numbers. M0b complete; M1 (printed housing,
  battery, BLE records) is next.

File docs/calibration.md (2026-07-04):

# Calibration

> Stub — calibration ships with v0.2 (milestone M4). See SPEC.md §4.

Planned procedure: button-triggered 2-second rest on the stadium floor (or a
rim jig) zeroes the IMU orientation to the stadium plane; the offset is
stored in NVS. Launch angle is then reported relative to that plane.

Nothing to calibrate in v0.1 — spin (RPM) measurement needs no calibration.

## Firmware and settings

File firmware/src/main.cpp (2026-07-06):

// OpenRip M0 — optical spin sensing, presence-gated (SPEC.md §4, §8).
//
// Polls a TCRT5000 IR reflective sensor aimed at the winder launcher's
// factory encoder disc (software Schmitt trigger, thresholds in config.h)
// and a plunger microswitch that reports bey presence. Launch detection is
// a state machine:
//
//   IDLE ──plunger high──▶ ARMED ──first pulse──▶ RIPPING ──plunger falls──▶ report
//
// The plunger falling edge timestamps the release; the record carries both
// peak RPM (min interval) and release RPM (last interval before the edge).
// Pulses are ignored while the plunger is low, so winding/re-insertion
// can't fake a launch. The 250ms pulse timeout survives only as a fallback
// for a missed release edge. Send 'r' over serial to toggle raw mode
// (streams "micros,adc" for signal characterization). BLE is a no-op
// unless built with -DOPENRIP_ENABLE_BLE.

#include <Arduino.h>

#include "config.h"
#include "launch_record.h"
#include "ble_service.h"

#ifdef OPENRIP_ENABLE_SLEEP
#include <esp_sleep.h>
#endif

// --- Launch state machine -------------------------------------------------------

enum class LaunchState : uint8_t { IDLE, ARMED, RIPPING };

static LaunchState g_state = LaunchState::IDLE;

static const char *stateName(LaunchState s) {
    switch (s) {
        case LaunchState::IDLE:    return "IDLE";
        case LaunchState::ARMED:   return "ARMED";
        default:                   return "RIPPING";
    }
}

static void setState(LaunchState s) {
    if (s == g_state) return;
    g_state = s;
    Serial.printf("# state: %s\n", stateName(s));
}

// --- Plunger (bey presence) -------------------------------------------------------

static bool     g_beyPresent        = false; // debounced state
static bool     g_plungerRaw        = false;
static uint32_t g_plungerRawSinceMs = 0;
static uint32_t g_plungerRawEdgeUs  = 0;     // micros() of the raw edge under debounce

// Debounced read. Returns true when the stable state just changed;
// g_plungerRawEdgeUs then holds the timestamp of the raw edge that started
// the transition (closer to the physical event than the debounce-confirm
// time).
static bool updatePlunger() {
    const bool raw = (digitalRead(PIN_PLUNGER) == LOW); // pressed = bey present
    if (raw != g_plungerRaw) {
        g_plungerRaw        = raw;
        g_plungerRawSinceMs = millis();
        g_plungerRawEdgeUs  = micros();
    }
    if (raw != g_beyPresent && millis() - g_plungerRawSinceMs >= PLUNGER_DEBOUNCE_MS) {
        g_beyPresent = raw;
        return true;
    }
    return false;
}

// --- Pulse capture ------------------------------------------------------------

static uint32_t g_pulseCount     = 0;
static uint32_t g_firstPulseUs   = 0;
static uint32_t g_lastPulseUs    = 0;
static uint32_t g_minIntervalUs  = UINT32_MAX; // shortest interval = peak RPM
static uint32_t g_lastIntervalUs = 0;          // latest interval = instantaneous/release RPM
static bool     g_schmittArmed   = true;       // waiting for a LOW crossing
static bool     g_rawMode        = false;

static void registerPulse(uint32_t now) {
    if (g_pulseCount == 0) {
        g_firstPulseUs = now;
        g_lastPulseUs  = now;
        g_pulseCount   = 1;
        return;
    }
    const uint32_t interval = now - g_lastPulseUs;
    // Glitch filter: noise spikes are dropped without moving the last-pulse
    // anchor, so the next real pulse still times correctly.
    if (interval >= MIN_PULSE_INTERVAL_US) {
        if (interval < g_minIntervalUs) g_minIntervalUs = interval;
        g_lastIntervalUs = interval;
        g_lastPulseUs    = now;
        g_pulseCount++;
    }
}

// One ADC sample through the software Schmitt trigger. A reflective feature
// (white segment) pulls the reading LOW; falling below SENSOR_THRESH_LOW is
// a pulse, and the detector re-arms above SENSOR_THRESH_HIGH. Pulses only
// register while a bey is present (SPEC §4) — the Schmitt state still
// tracks so the first armed pulse is clean.
static void sampleSensor() {
    const uint32_t now = micros();
    const int adc = analogRead(PIN_SENSOR);

    if (g_rawMode) {
        // Serial is the throughput bottleneck (~700 lines/s at 115200) —
        // that is still "max rate" for characterization purposes.
        Serial.printf("%lu,%d\n", (unsigned long)now, adc);
    }

    if (g_schmittArmed && adc < SENSOR_THRESH_LOW) {
        if (g_beyPresent) registerPulse(now);
        g_schmittArmed = false;
    } else if (!g_schmittArmed && adc > SENSOR_THRESH_HIGH) {
        g_schmittArmed = true;
    }
}

// --- Helpers ------------------------------------------------------------------

// Hook RPM from a pulse interval: encoder RPM scaled by the gear ratio
// (GEAR_RATIO, config.h — confirmed 1.0: the encoder disc sits on the hook
// shaft).
static uint32_t rpmFromIntervalUs(uint32_t intervalUs) {
    if (intervalUs == 0) return 0;
    const uint64_t encoderRpm = 60000000ULL / ((uint64_t)intervalUs * PULSES_PER_REV);
    return (uint32_t)((float)encoderRpm * GEAR_RATIO + 0.5f);
}

static void resetCapture() {
    g_pulseCount     = 0;
    g_firstPulseUs   = 0;
    g_lastPulseUs    = 0;
    g_minIntervalUs  = UINT32_MAX;
    g_lastIntervalUs = 0;
}

static void reportLaunch(bool viaReleaseEdge) {
    static uint16_t s_seq = 0;

    const uint32_t durationMs = (g_lastPulseUs - g_firstPulseUs) / 1000;
    const uint32_t peakRpm    = rpmFromIntervalUs(g_minIntervalUs);
    const uint32_t releaseRpm = rpmFromIntervalUs(g_lastIntervalUs);
    // pulseCount-1 intervals over the launch window
    const uint32_t avgRpm = durationMs > 0
        ? rpmFromIntervalUs((g_lastPulseUs - g_firstPulseUs) / (g_pulseCount - 1))
        : peakRpm;

    launch_record_t rec = {};
    rec.seq             = s_seq++;
    rec.peak_rpm        = (uint16_t)min(peakRpm, (uint32_t)UINT16_MAX);
    rec.release_rpm     = (uint16_t)min(releaseRpm, (uint32_t)UINT16_MAX);
    rec.rip_duration_ms = (uint16_t)min(durationMs, (uint32_t)UINT16_MAX);
    rec.battery_pct     = 100; // USB-powered on the breadboard; real gauge lands with M1

    Serial.println(F("---- LAUNCH ----"));
    Serial.printf("seq:         %u\n", rec.seq);
    Serial.printf("peak RPM:    %u\n", rec.peak_rpm);
    Serial.printf("release RPM: %u\n", rec.release_rpm);
    Serial.printf("avg RPM:     %lu\n", (unsigned long)avgRpm);
    Serial.printf("duration:    %u ms\n", rec.rip_duration_ms);
    Serial.printf("pulses:      %lu (%d/rev)\n", (unsigned long)g_pulseCount, PULSES_PER_REV);
    Serial.printf("end trigger: %s\n", viaReleaseEdge ? "release edge" : "pulse timeout (fallback)");
    Serial.println(F("----------------"));

    bleNotifyLaunch(rec);
}

// --- Power management (M1) ----------------------------------------------------

#ifdef OPENRIP_ENABLE_SLEEP
// Millis timestamp of the last thing worth staying awake for: boot, a bey
// seated/ripping, or a connected BLE client.
static uint32_t s_lastActivityMs = 0;

static void goToSleep() {
    Serial.println(F("Idle — deep sleeping. Press button to wake."));
    Serial.flush();
    // Wake on button press (active low, internal pull-up). C3 deep-sleep GPIO
    // wake is limited to GPIO0–5; PIN_BUTTON must stay in that range.
    // TODO(M1 hardware): confirm the internal pull-up holds through deep
    // sleep on the XIAO; add an external 100k pull-up if it doesn't.
    esp_deep_sleep_enable_gpio_wakeup(1ULL << PIN_BUTTON, ESP_GPIO_WAKEUP_GPIO_LOW);
    esp_deep_sleep_start();
}
#endif

// --- Arduino entry points -------------------------------------------------------

void setup() {
    Serial.begin(SERIAL_BAUD);
    delay(200);

    pinMode(PIN_SENSOR, INPUT);
    analogReadResolution(12);
    pinMode(PIN_PLUNGER, INPUT_PULLUP);

#ifdef OPENRIP_ENABLE_SLEEP
    pinMode(PIN_BUTTON, INPUT_PULLUP);
    s_lastActivityMs = millis();
#endif

    bleInit();

    Serial.println(F("OpenRip M0 — presence-gated optical spin proof."));
    Serial.println(F("Send 'r' for raw ADC mode. Lock a bey in to arm."));
}

void loop() {
    // Serial commands: 'r' toggles the raw ADC stream.
    if (Serial.available()) {
        const char c = (char)Serial.read();
        if (c == 'r' || c == 'R') {
            g_rawMode = !g_rawMode;
            Serial.printf("# raw mode %s (thresholds: low=%d high=%d)\n",
                          g_rawMode ? "ON — us,adc" : "OFF",
                          SENSOR_THRESH_LOW, SENSOR_THRESH_HIGH);
        }
    }

    const bool plungerChanged = updatePlunger();
    sampleSensor();

#ifdef OPENRIP_ENABLE_SLEEP
    if (g_state != LaunchState::IDLE || bleIsConnected()) s_lastActivityMs = millis();
    if (millis() - s_lastActivityMs >= IDLE_SLEEP_TIMEOUT_MS) goToSleep();
#endif

    switch (g_state) {
        case LaunchState::IDLE:
            if (plungerChanged && g_beyPresent) {
                resetCapture();
                setState(LaunchState::ARMED);
            }
            break;

        case LaunchState::ARMED:
            if (plungerChanged && !g_beyPresent) {
                // Bey removed without a rip — disarm quietly.
                setState(LaunchState::IDLE);
            } else if (g_pulseCount > 0) {
                setState(LaunchState::RIPPING);
            }
            break;

        case LaunchState::RIPPING: {
            if (plungerChanged && !g_beyPresent) {
                // RELEASE: the plunger falling edge is the launch end.
                // g_plungerRawEdgeUs is the physical edge time; release RPM
                // comes from the last pulse interval before it.
                if (g_pulseCount >= MIN_PULSES_PER_LAUNCH) {
                    reportLaunch(true);
                } // else: stray pulse while seated — not a launch
                resetCapture();
                setState(LaunchState::IDLE);
                break;
            }
            // Fallback: release edge missed (or bey spun down while still
            // seated) — a pulse gap ends the launch. Bey is still present,
            // so return to ARMED for the next rip.
            if (micros() - g_lastPulseUs >= LAUNCH_END_TIMEOUT_MS * 1000UL) {
                if (g_pulseCount >= MIN_PULSES_PER_LAUNCH) {
                    reportLaunch(false);
                }
                resetCapture();
                setState(LaunchState::ARMED);
                break;
            }
            // Still ripping: push live RPM for training mode (no-op without BLE).
            static uint32_t s_lastLiveMs = 0;
            const uint32_t nowMs = millis();
            if (g_lastIntervalUs > 0 && nowMs - s_lastLiveMs >= LIVE_RPM_PERIOD_MS) {
                s_lastLiveMs = nowMs;
                bleUpdateLiveRpm((uint16_t)min(rpmFromIntervalUs(g_lastIntervalUs), (uint32_t)UINT16_MAX));
            }
            break;
        }
    }
}

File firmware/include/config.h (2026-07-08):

#pragma once

// ---------------------------------------------------------------------------
// OpenRip firmware configuration — pin assignments and tunables.
// Board: Seeed XIAO ESP32-C3. See /hardware/wiring.md for sensor hookup.
// ---------------------------------------------------------------------------

// --- Pins -------------------------------------------------------------------

// TCRT5000 phototransistor output (analog). A1 = GPIO3 on the XIAO ESP32-C3
// (ADC-capable). Wiring: collector to this pin with a 10k pull-up to 3V3,
// emitter to GND — more reflection pulls the reading LOW.
#define PIN_SENSOR A1

// --- Optical sensing tunables -------------------------------------------------
// Target (M0a, confirmed): the winder launcher's factory encoder disc —
// black/white two-segment, seen through the ~5x5mm top-face window, disc
// surface ~3mm below. Measured M0b (2026-07, hand-crank capture): quiet
// baseline ~190-230, rotation peaks vary 600-2400+ with crank speed —
// thresholds picked to clear the baseline noise floor and still re-arm on
// the weakest observed peaks (~600).

// Software Schmitt trigger, 12-bit ADC counts (0–4095). A pulse registers
// when the reading falls below LOW (reflective feature in view); the
// detector re-arms when it rises back above HIGH. Gap between them is the
// hysteresis — keep it wider than the observed noise band.
#define SENSOR_THRESH_LOW  400
#define SENSOR_THRESH_HIGH 550

// Confirmed M0a: two-segment encoder disc = one dark/light cycle per
// encoder revolution. Used directly in the RPM math.
#define PULSES_PER_REV 1

// CONFIRMED (teardown, 2026-07): the encoder disc is mounted directly on
// the hook shaft (16T gear), downstream of the gear train — the window
// reads hook RPM directly, so the ratio is exactly 1.0. The constant stays
// for potential future launcher variants where the encoder sits elsewhere:
// hook_rpm = encoder_rpm * GEAR_RATIO.
#define GEAR_RATIO 1.0f

// Glitch filter: reject pulse intervals shorter than this. Size it from
// PULSES_PER_REV and max plausible RPM: at 15,000 RPM (250 rev/s) and
// 8 pulses/rev, real intervals are ~500µs — so 200µs rejects noise without
// eating real pulses. Retune when M0a fixes the real pulses/rev.
#define MIN_PULSE_INTERVAL_US 200UL

// --- Bey presence (plunger microswitch) ----------------------------------------

// Lever microswitch riding the launcher's spring plunger (rises above flush
// with a bey locked in, drops on release). D3 = GPIO5 on the XIAO ESP32-C3.
// COM → this pin (internal pull-up), NO → GND: bey present reads LOW.
#define PIN_PLUNGER D3

// Debounce window for the plunger switch.
#define PLUNGER_DEBOUNCE_MS 5UL

// --- Launch detection -----------------------------------------------------------

#define SERIAL_BAUD 115200

// FALLBACK ONLY (SPEC §4): the plunger release edge is the primary
// launch-end trigger; this timeout catches a missed edge — no pulse for
// this long while ripping ends the launch.
#define LAUNCH_END_TIMEOUT_MS 250UL

// Ignore "launches" with fewer pulses than this (a lone pulse gives no
// interval, so no RPM).
#define MIN_PULSES_PER_LAUNCH 2

// How often to push live RPM to the BLE training-mode stream while spinning
// (no-op in serial-only builds).
#define LIVE_RPM_PERIOD_MS 100UL

// --- Power (SPEC §4, builds with -DOPENRIP_ENABLE_SLEEP) ----------------------

// Wake/user button, wired to GND (internal pull-up). D2 = GPIO4 on the XIAO
// ESP32-C3; deep-sleep GPIO wake on the C3 only works on GPIO0–5.
#define PIN_BUTTON D2

// Deep sleep after this long with no pulses and no BLE client (SPEC: 5 min).
#define IDLE_SLEEP_TIMEOUT_MS (5UL * 60UL * 1000UL)

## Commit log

2026-07-04 Scaffold repo through M0 and M1 skeleton
    - /firmware: PlatformIO project (XIAO ESP32-C3, Arduino) implementing M0
    hall-sensor RPM over serial; BLE GATT stub behind OPENRIP_ENABLE_BLE
    with the v1 launch record schema from SPEC.md
    - /hardware: BOM.csv and wiring.md (A3144 digital / SS49E analog options)
    - /app, /docs, /models: placeholders and skeletons per SPEC.md §7
    - README with trademark note and milestone status; lean CLAUDE.md
    [BOM.csv]
2026-07-04 Add ESP Web Tools flash page stub
    app/flash/: install-button page (esp-web-tools 10.2.1 pinned with SRI)
    plus an ESP32-C3 manifest pointing at the merged release binary that
    ships at M3. Merged-bin recipe noted in the build guide.
2026-07-04 M2 Web Bluetooth app + M1 firmware: BLE build and idle deep sleep
    - /app: vanilla JS Web Bluetooth app — connect, live RPM gauge, launch
    history in localStorage, CSV export, sim mode for UI testing without
    hardware. Parses the packed v1 launch record (little-endian, 10 bytes).
    - Pages deploy workflow publishing /app on pushes to main
    - firmware: v01-device env (replaces ble-stub) adds OPENRIP_ENABLE_SLEEP —
    deep sleep after 5 min with no pulses and no BLE client, button wake on
    D2/GPIO4; bleIsConnected() accessor
    - README milestone statuses updated
    [config.h, main.cpp]
2026-07-04 Move Pages deploy off Actions — gh token lacks workflow scope
    Publish /app via a gh-pages branch instead (git subtree split). The
    Actions workflow can return once the token has workflow scope.
2026-07-04 Add @openrip/design system and sync it to Claude Design
    design/: React+TS package codifying the app's garage-dyno look — 8
    components (Button, StatusChip, Gauge, StatTile, HazardStripe, Banner,
    Wordmark, DataTable) with tokens mirrored from app/style.css.
    .design-sync/: sync config, authored previews, conventions header, notes.
2026-07-05 Design refresh: clean and bold — Outfit, single family, no industrial ornament
    - Single typeface (Outfit), weight-driven hierarchy; drops Chakra Petch
    and IBM Plex Mono
    - Rounded corners replace clip-paths; glows, scanlines, and hazard
    stripes removed; letterspacing calmed; sentence case
    - HazardStripe component renamed to Divider (clean accent fade rule)
    - Applied to both @openrip/design (re-synced to Claude Design) and the
    live web app so they stay mirrored
2026-07-05 Identity reset: open=rip — light editorial zine (ray=out direction)
    Scraps the dark dyno look for paper-white editorial: Instrument Sans
    with italics, hairline rules instead of boxes, trapar-teal accent,
    lowercase open=rip wordmark with teal equals, pill buttons, top-rule
    stat blocks. Same component APIs; DS re-synced to Claude Design and the
    live app restyled to match.
2026-07-05 BOM: real supplier links, purchase notes, M0/M1 split
    [BOM.csv]
2026-07-06 Pivot to non-contact optical sensing (QRE1113) — zero launcher modification
    The glued-magnet approach modified the launcher, killing tournament
    viability. Switch to a QRE1113 IR reflective sensor reading the stock
    spool through the BattlePass mount opening, matching how the official
    module senses.
    - SPEC: zero-modification hard goal; QRE1113 in the v0.1 BOM with a
    removable-sticker fallback; risk is now optical signal quality off
    stock geometry; M0 split into M0a (mount characterization, gating)
    and M0b (sensor proof); open questions on pulses/rev and
    TO-discretion tournament legality
    - Firmware: ADC polling with software Schmitt trigger replaces the
    hall interrupt; thresholds,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
    [BOM.csv]
2026-07-06 M0a complete: factory encoder confirmed — TCRT5000, real constants
    M0a findings: the winder launcher has a factory optical encoder (two-
    segment black/white disc, ~5x5mm top-face window, disc ~3mm below) —
    zero-modification sensing confirmed viable; this is the surface the
    official device reads. Signal risk downgraded to low; remaining unknown
    is IR contrast of the translucent white segment.
    - Sensor: TCRT5000 primary (~2.5mm sensitivity peak matches the 3mm
    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
    [BOM.csv]
2026-07-06 Gear ratio confirmed 1.0 — encoder disc is on the hook shaft
    Teardown: the disc mounts directly on the hook shaft (16T gear),
    downstream of the gear train, so the window reads hook RPM directly.
    GEAR_RATIO stays as a constant for future launcher variants. M0a fully
    complete; SPEC §9 open question resolved.
    [config.h]
2026-07-06 Bey-presence input: plunger microswitch, state machine, release RPM
    The winder has a spring plunger beside the encoder window that rises
    above flush when a bey is locked and drops at release. A low-force
    lever microswitch (Omron SS-01GL class) rides it as a presence input.
    - Firmware: launch detection is now a presence-gated state machine
    (IDLE -> ARMED -> RIPPING -> release on the plunger falling edge);
    pulses ignored while unarmed, killing winding/re-insertion false
    positives. Release edge timestamped; record carries release_rpm from
    the last interval before the edge. 250ms timeout kept only as a
    missed-edge fallback (returns to ARMED, bey still seated). ~5ms
    switch debounce;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
    [BOM.csv]
2026-07-06 Adjustable switch carriage for ~1mm plunger travel
    Fixed switch placement can't survive FDM tolerance stack-up against
    ~1mm of plunger rise. SPEC §6: microswitch mounts on a slot + M2 screw
    carriage, calibrated once per build (clicks seated, releases empty).
    Calibration procedure added to the build guide; BOM tightens the switch
    requirement to <0.5mm differential travel / <0.5N force (D2F-01FL
    class) and adds the carriage fastener. No firmware changes.
    [BOM.csv]
2026-07-06 README: catch up to the optical pivot and M0a findings
    Winder-launcher top-face mount (not string-launcher clip-on), TCRT5000
    reading the factory encoder disc, presence switch + release RPM in the
    feature list, M0a marked complete in the roadmap.
2026-07-07 Add ASCII wiring diagrams to hardware/wiring.md
    Rail-style diagrams for the TCRT5000 (LED branch + phototransistor
    pull-up divider) and the plunger microswitch, alongside the existing
    pin tables.
2026-07-08 M0b sensor proof: passed — thresholds tuned from real hand-crank data
    Set SENSOR_THRESH_LOW/HIGH from a real breadboard capture (baseline
    ~190-230, peaks 600-2400+) instead of the M0a placeholders, which
    would have failed to re-arm on weaker cranks. Real launch tests
    confirm peak RPM in the expected 5,000-12,000 hook-RPM range.
    Marks M0b complete across SPEC.md, README.md, and the build docs;
    logs the raw findings in docs/sensor-characterization.md. Also
    gitignores firmware/logs/ (pio device monitor's log2file output).
    [config.h]
2026-07-09 Add M1 housing design spec: Blender + MCP scan-based workflow
    Brainstormed approach for the printable two-part shell: phone 3D scan
    of the launcher top face as a registration reference, Blender driven
    via MCP for modeling (chosen over FreeCAD/OpenSCAD for its scan-mesh
    handling), FreeCAD as a narrow STL->STEP conversion bridge at export.
2026-07-09 Add M1 housing implementation plan (Blender + MCP scripted workflow)
    Nine-task plan from scan capture through print/fit-test loop. Mixes
    agent-scriptable Blender/FreeCAD steps with explicit human-action
    steps (scanning, measuring, printing, fit-testing) since those can't
    be automated. Self-review caught and fixed a dimension bug in the
    sensor-carrier pocket math and replaced a vague snap-tab deferral
    with concrete dimension-reading code.
2026-07-14 M1 deck: carriage for IR sensor + microswitch, slide-switch bay
    components.blend: bare TCRT5000 sensor separated from the breakout
    module (tcrt5000_ir_sensor / tcrt5000_board); scan holes patched.
    components_carriage.blend (new): BP_gear_port remodel finalized as
    OpenRip_Deck — symmetrized from the -X half, watertight (5775.6 mm3,
    0 boundary / 0 non-manifold). Adds sensor collar over the -Y window
    (+0.15 fit), Omron D2FC ring (+0.2 fit, seat contact preserved),
    open-top slide-switch notch through the +Y rim with snap-over
    retention lips (0.45 mm overhang, 0.25 mm clearance). Zero deck
    interference with sensor and switch, verified via world-space BVH.
    Booleans use the MANIFOLD solver —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
